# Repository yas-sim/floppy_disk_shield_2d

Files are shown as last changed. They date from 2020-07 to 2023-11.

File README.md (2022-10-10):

# Floppy Disk Shield for Arduino UNO

## Caveat and Disclaimer - Read before you build a fd-shield  

- I don't own any responsibility for the data loss or physical damage on your floppy disks or computer assets caused by the use of hardware and software included in this project.
- Hardware compatibility (especially, FDD and FD-Shield compatibility) is not guaranteed. Your FDD may now work with the FD-Shield.  
- The magnetic flux power on the old floppy disks are dropping and getting weak as time passes. Read-out data integrity with this system is not guaranteed.
- Recommended to use newer FDD. The old FDD may have problems on the magnetic head such as contamination, worn out or mechanical misalignment.

## Announcement  
23-Sep 2022 : Preview release - Feature to write back the floppy images to FD is supported. Use `duplicate.py` to write the `*.raw` floppy image data to a floopy disk. Arduino firmware update and closing `JP5` on the fd-capture shield are required to enable the feature.   
23-Sep 2022 : Preview release - イメージの書き戻しもできるようになりました。Arduinoファームウエアの更新と`JP5`ジャンパーのショートをすると書き込みができるようになります。   

## Description
This is a project to develop a system for preserving old 2D/2DD floppy disk data.  
The system can preserve entire floppy disk data regardless whether it's normal or not. That means the system can read and preserve copy protect information in the bit-stream file as it is.  
The recorded bit-stream file can be decoded and restore the contents anytime later.  
The system includes a bit-stream data to D77/D88 emulator disk image converter. You can read the floppy disk with this tool and generate the disk images.  
これは古い2D/2DDフロッピーディスクのデータを保存するためのシステムを作るプロジェクトです。  
このシステムを使うことで仕様にのっとった正しい信号も非正規の信号も全てそのまま保存することが可能です。つまり、このシステムではコピープロテクトのための情報まで含めてビットストリームデータとして保存することが可能です。  
記録されたビットストリームデータは後でデコード、解読を行うことで情報を取り出すことが可能です。  
このシステムにはビットストリームデータからエミュレータ互換のイメージファイル(D77/D88)を生成するためのコンバーターも含んでいます。実際のフロッピーを読み取り、ディスクイメージを生成することが可能です。  

The system consists of the hardware and software:  
システムはハードウエアとソフトウエアから構成されます:

**Hardware**  
|Item|Description|
|:----|:----|
|Arduino UNO|Arduino UNO. The firmware uses ATMega328 specific regiter. The other Arduino board may not work|
|Floppy disk shield for Arduino|Design data is included. Both schematics and PCB data are available (`./kicad/*`)<br>Rev.A design has bugs. Rev.B and beyond are basically comatible and has same function.<br>KiCAD用のPCBの設計データも提供されています(./kicad/*)<br>Rev.A and Rev.Fにはバグがあります。Rev.B以降は基本的に同じ機能です|
|Floppy disk drive|2D/2DD/2HD FDD. 3.5" or 5.25" FDD (+ power supply and ribbon cable). 300rpm drive is recommended but 360rpm 2HD drive will work as a 2DD drive. The FD-shield can detect the track density (2D or 2DD/2HD, 80 tracks or 160 tracks) and spindle spin speed (300rpm or 360rpm)|  

**Software**  

|Name|Description|
|:---|:---|
|[`fdcapture.ino`](./docs/fdcapture_ino.md)|Arduino firmware (sketch) for the floppy shield<br> (`./fdcapture/fdcapture.ino`)|
|[`capture.py`](./docs/capture.md)|Floppy image capture tool (FD->image).<br>Transfers raw bitstream data from Arduino to a PC (foremerly, `transfer.py`)|
|[`duplicate.py`](./docs/duplicate.md)|Floppy image write back tool (image->FD).<br>Transfers raw bitstream data from a PC to Arduino. Close '`JP5`' jumper pad on the FD capture shield to enable the write feature.|
|[`bs2d77.py`](./docs/bs2d77.md)|Bit-stream data (.raw) to emulator disk image (D77/D88) converter.<br> The program generates modified D77 image data (D77mod). D77mod specification is [here](docs/D77mod_format.md). The D77mod uses some reserved bytes in the header but it is designed to keep backward compatibility with the standard D77 disk images. The D77mod image should work with emulators which supports regular D77/D88 disk images.|
|[`bs2hfe`](./docs/bs2hfe.md)|Bit-stream data (.raw) to .HFE floppy image format.<br>The .hfe disk image format is used for the [HxC FDD emulator device](https://hxc2001.com/download/floppy_drive_emulator/).|
|[`bs_inspect.py`](./docs/bs_inspect.md)|Data inspection/analyze tool for bit-stream data|
|[`d77_inspect.py`](./docs/d77_inspect.md)|Data inspection/analyze tool for D77/D88 disk image data|
|`floppylib.py`|A library which provides fundamental floppy disk functions.<br> This library is including data-separator, digital VFO, MFM decoder and IBM format parser|
|`d77dec.py`|Convert a D77/D88 disk image data to a JSON (plane text) file|
|`d77enc.py`|Generate a D77/D88 disk image data from a JSON file|
|`d77lib.py`|A libray which provides basic D77/D88 floppy disk image manipulation functions|
|[`kfx2bs.py`](./docs/kfx2bs.md)|[**KyroFlux**](https://www.kryoflux.com/) raw-bitstream data to fd-shield bit-stream data converter. You can capture FD image with KryoFlux and use it.|

### Updates  
|Date|Description|
|-|-|
|Sep 2022|Updated PCB design. Changed the 'Write Gate' jumper from jumper pad to jumper pin header for easy setting.|
|Sep 2022|Added support for the image write back feature (image->fd). Arduino firmware update and closing `JP5` on the fd-capture shield are required to enable the feature.|
|Sep 2022|Added RAW to HFE file converter (bs2hfe.py)|
|Aug 2022|Backported data-separator and VFO algorithm from [fdc_bitstream](https://github.com/yas-sim/fdc_bitstream) project. The latest VFO algorithm improved the accuracy of the data reading / decoding.|

## fdc_bitstream  
The [`fdc_bitstream`](https://github.com/yas-sim/fdc_bitstream) is my project that provides a bit-accurate C++ software FDC library. The fdc_bitstream project includes a disk image converter and image analyzer. Those software are written in C++, so they are faster than the converters in this project. Also, they are developed recently and have better algorithms for format conversion.  Please try `image_converter` in the `fdc_bitstream` project as well.  
[`fdc_bitstream`](https://github.com/yas-sim/fdc_bitstream)はビット精度で正確なソフトウエアFDCを開発するプロジェクトです。fdc_bitstreamプロジェクトにもイメージ変換ツールとイメージ解析ツールが含まれています。これらのツールはC++でかかれており、より高速です。またこちらのほうが開発が後なのでより良いアルゴリズムが使われており、イメージ変換の正確性も上がっています。fdc_bitstreamプロジェクトのimage_converterもお試しください。  

### System Diagram
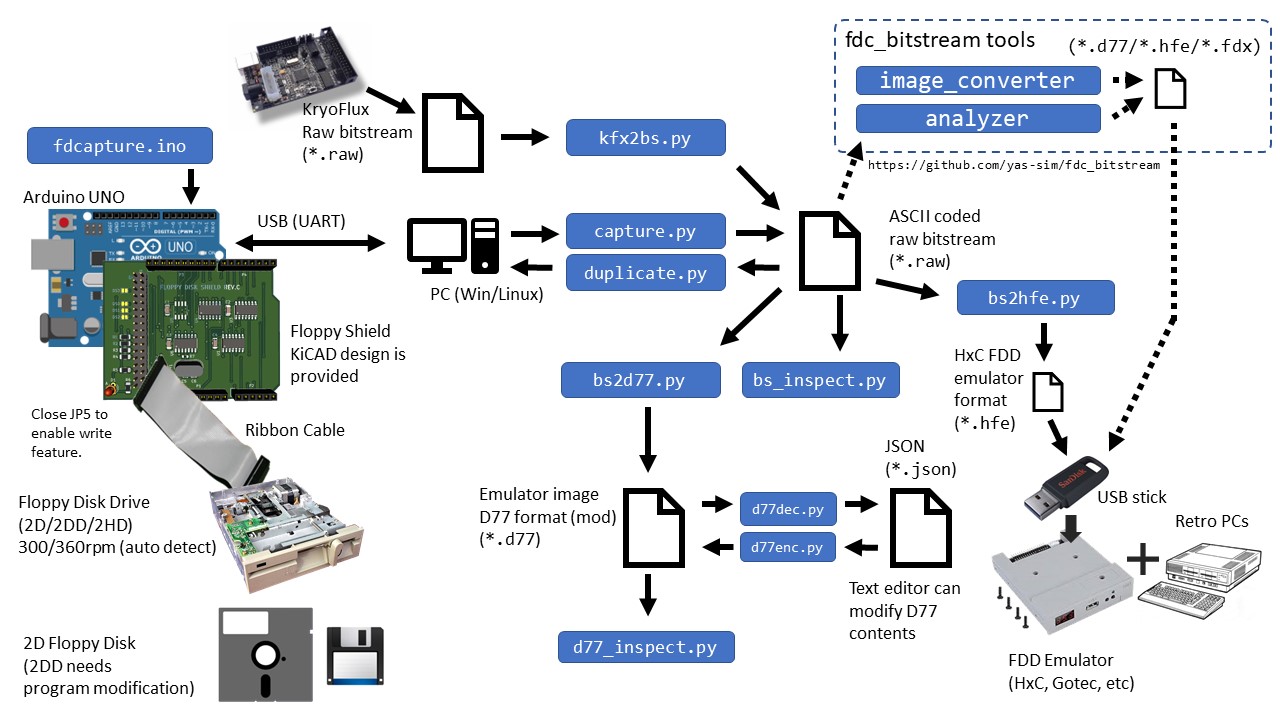
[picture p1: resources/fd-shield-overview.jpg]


## FD-Shield - How It Works
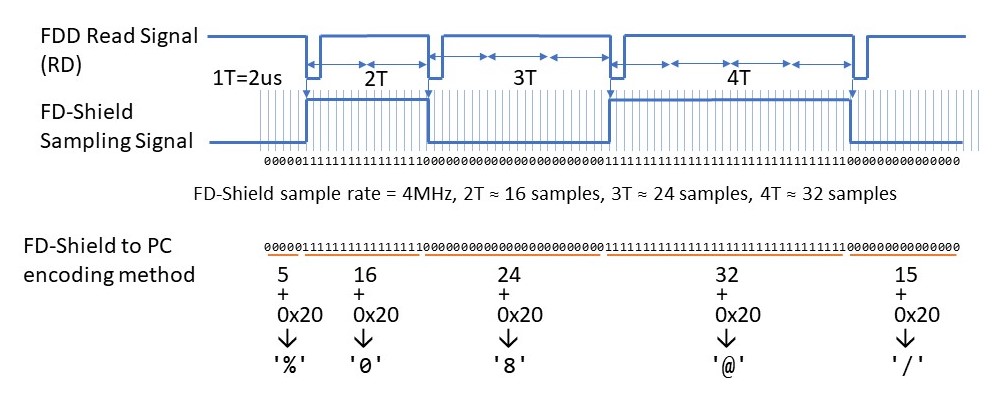
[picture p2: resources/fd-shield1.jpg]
FD_Shield How it works


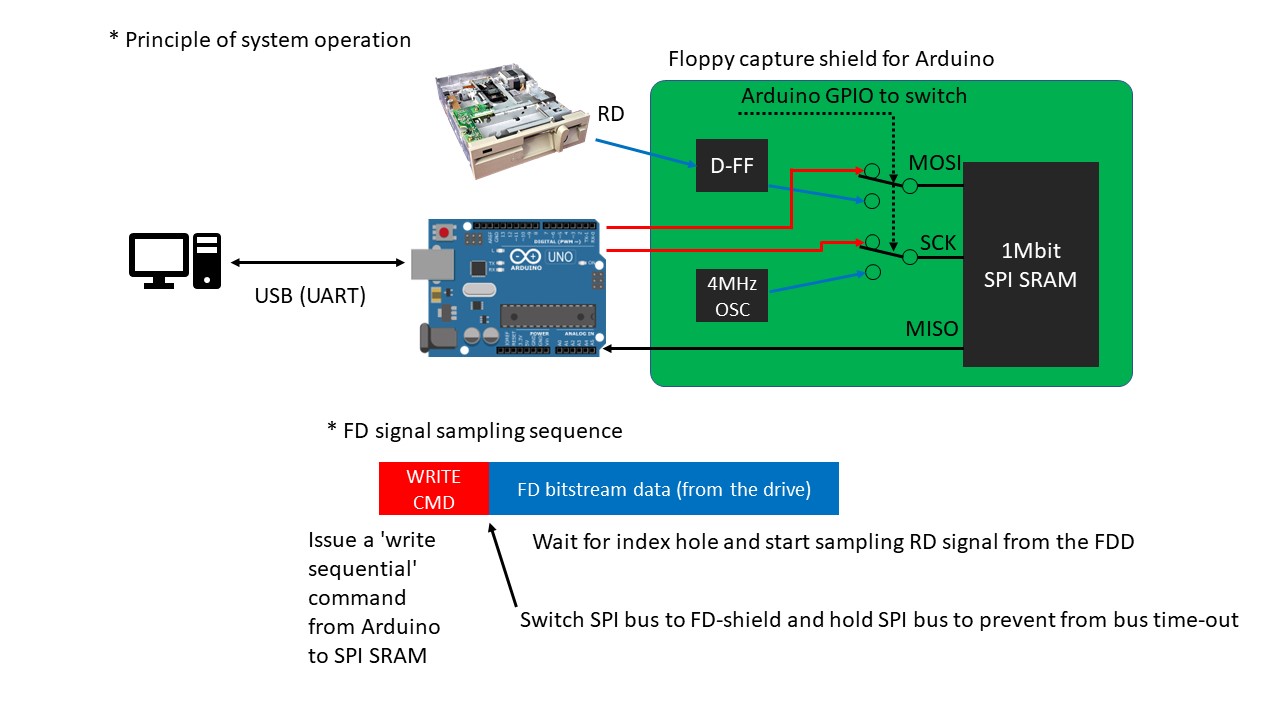
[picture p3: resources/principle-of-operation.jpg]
FD_Shield_Principal_of_operation


---------

## Introduction of Features in the Support Tools

* `bs_inspect.py`  
This tool provides featurs to analyze or check the bitstream data and its quality.  
	* Visualize track data including address mark and sector data occupancies.
	* Visualize data timing history.
	* Visualize data timing histogram.
	* Read all IDs in the tracks.
	* Read all sectors in the tracks.
	* MFM data dump.
	* ASCII data dump (display pritable/readable data).
	* Tweak parameters (VFO high/low gain value, sampling frequency, FDD spin speed) .

### Track visualizer  
You can check the address marks and sector body overlap status with this feature. The entire track data is shown in the window. The yellow vertical line indicates the position of the index hole (it appears when you capture the track data with --read_overlap option). This feature can show the decoded MFM data at the point of the mouse cursor.   

* Legend:  
	* Red ID               : ID CRC Error
	* Green virtical line  : ID AM / Index AM
	* Cyan virtical line   : DAM / DDAM
	* Cyan horizontal line : Sector data (normal)
	* Magenta horizontal line : Sector data (Data CRC error)
	* Red cross mark       : Record not found error
	* Yellow virtical line : Index hole  
<br>  

* Example of a normal track  
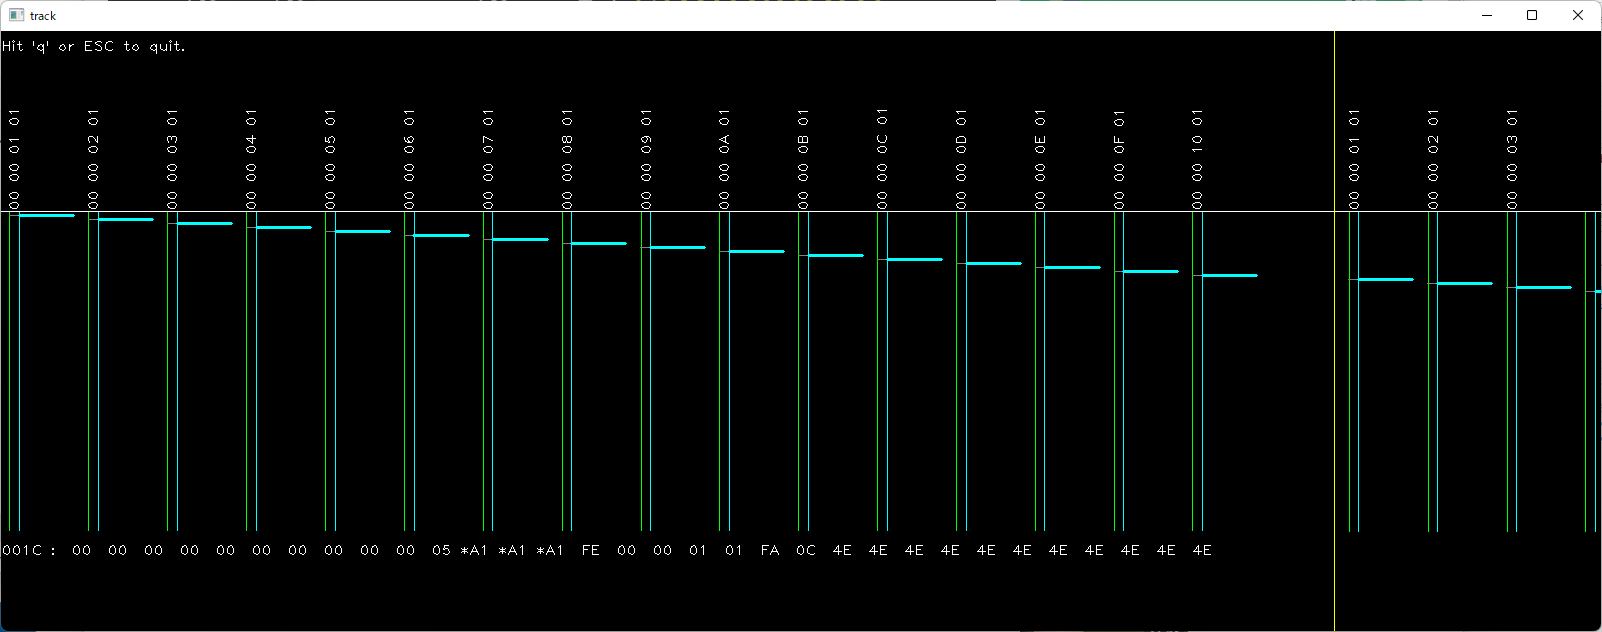
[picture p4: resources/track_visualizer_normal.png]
normal
  

* Example of a protected track  
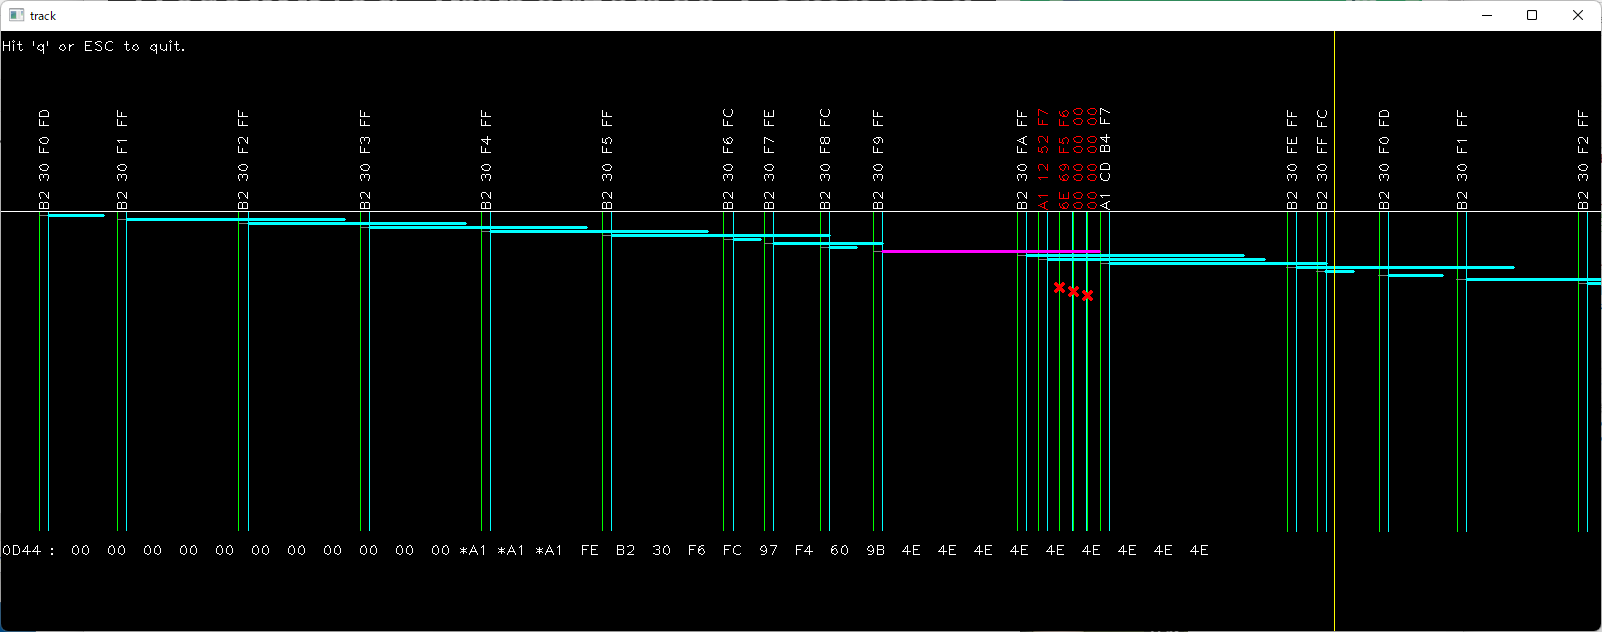
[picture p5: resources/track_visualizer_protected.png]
protected
  

### Bitstream visualizer  
You can check how VFO follows the variation of pulse pitch with the bitstream visualizer.  
The VFO tries to keep the data pulse be the center of the bit cell as much as possible by tweaking the oscillation frequency (= the bit cell width).  
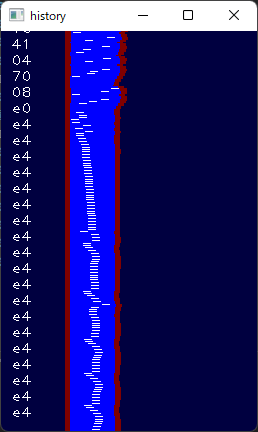
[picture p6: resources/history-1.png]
history-good

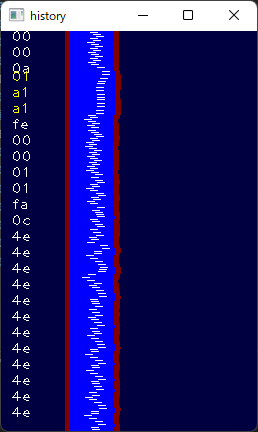
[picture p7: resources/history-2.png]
history-bad
  

### Bitstream timing histogram viewer
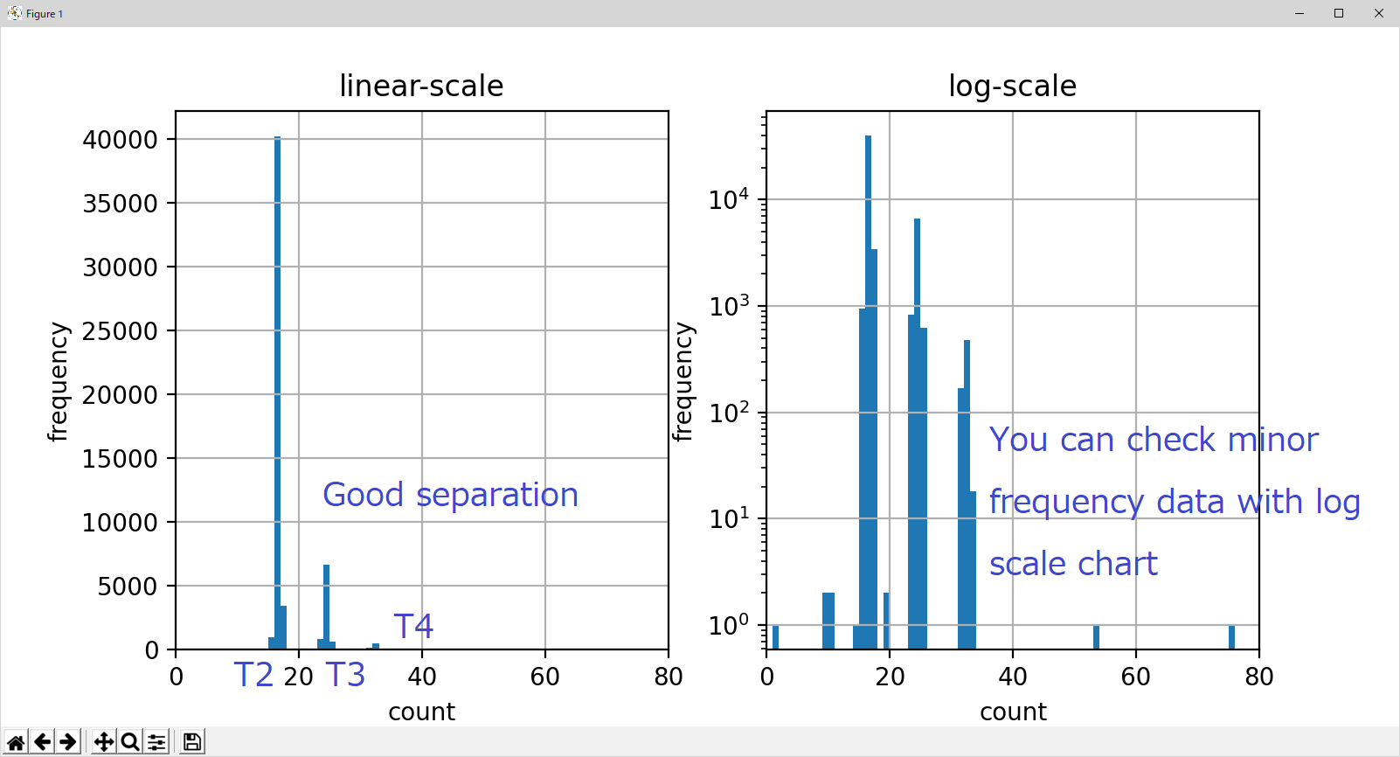
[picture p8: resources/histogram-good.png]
histogram-good
* Good case 
* Bad case - Usually, this may be caused by the spindle speed fluctuation (that causes data pulse pitch variation in a track), or data written by multiple drives (written with drives with different spindle motor speeds).  
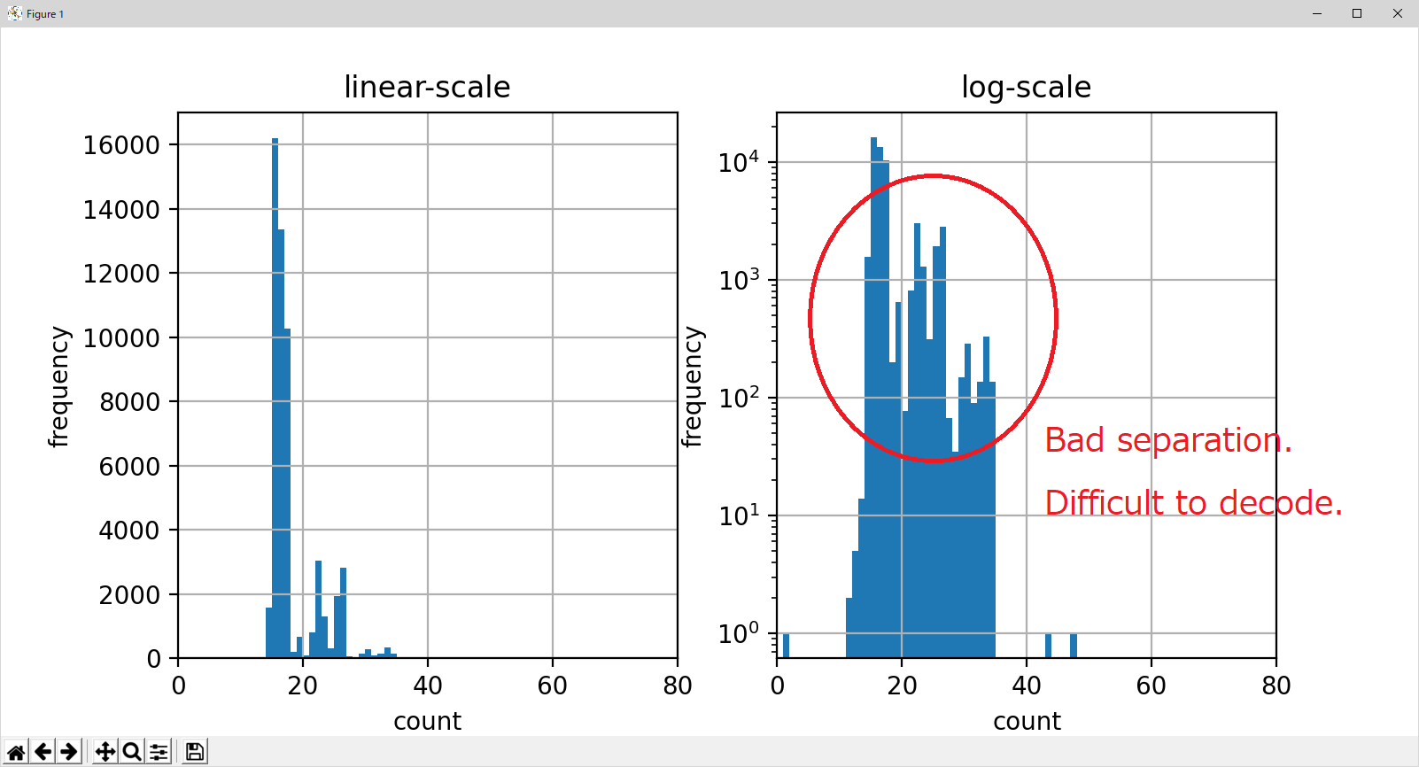
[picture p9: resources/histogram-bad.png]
histogram-bad

  
### Pulse (bit) pitch visualizer  
You can check the pulse pitch fluctuation throughout a track with the pulse pitch visualizer. The stabler pitch, the easier MFM decode or data read.  
- Stable pitch  
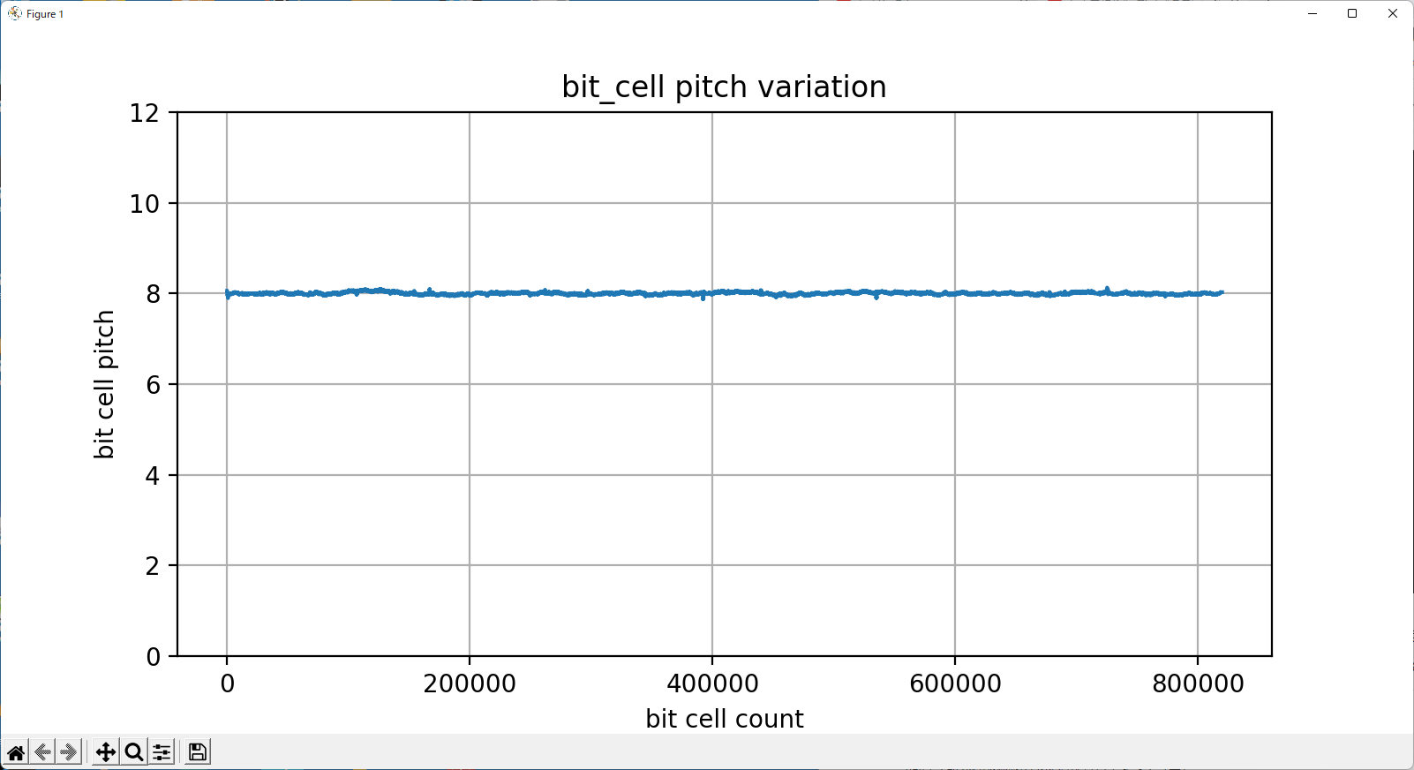
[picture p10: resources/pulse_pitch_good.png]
good pitch

- Unstable pitch. Heavily fluctuated. It's so hard to follow by the VFO. May fail data retrieving.  
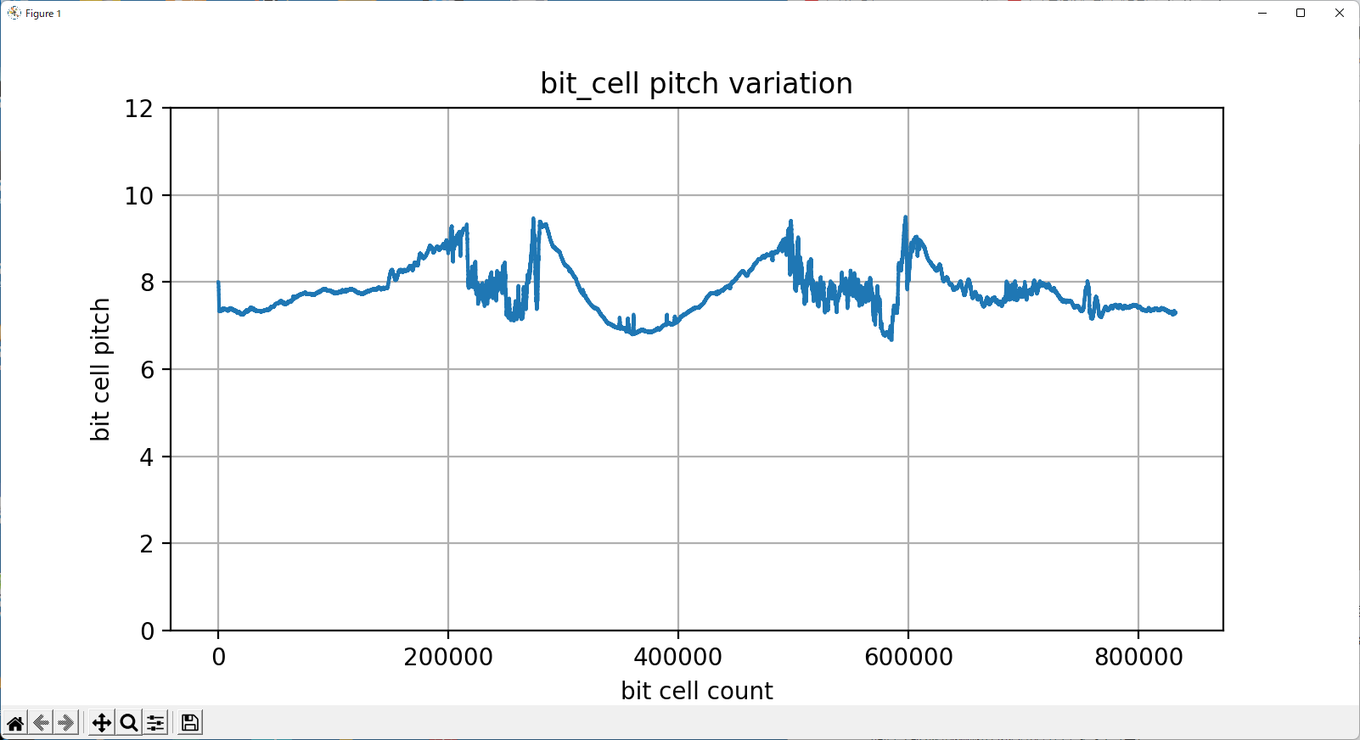
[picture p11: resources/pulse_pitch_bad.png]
bad pitch

 
---------

## How to use (Image capture) - 使い方

1. Build Floppy shield for Arduino UNO - シールド製作  
- PCB design files can be found in the `./kicad` directory
2. Burn the floppy disk shield firmware (sketch) to Arduino UNO - Arduio UNOにファームウエアを書き込む  
Use `fdcapture.ino`
3. Assemble the system - システムを接続
- Attach a floppy shield to an Arduino UNO
- Connect a floppy shield and a floppy disk drive with a 36pin ribon cable
- Connect Arduino UNO to PC via USB cable
4. Read raw bit-stream data from a floppy disk - フロッピーからビットストリームデータを生成  
- Insert a 2D floppy disk to the floppy disk drive (FDD)
- Run following command on the Windows PC:
```sh
python capture.py -o image_name.raw --read_overlap 5 [--media_type 2D|2DD]
```
- `capture.py` will search COM port for Arduino UNO and use it.  
- `--read_overlap` option specifies how much data to read on the 2nd lap in percent.  
- `--media_type` option specifies the media type to read. `2D` or `2DD` are available.  
Note: The `fdcapture.ino` can identify the drive type (2D or 2DD) but not the media type.    
5. Convert raw bit-stream data into emulator image data (D77mod) -- ビットストリームからディスクイメージファイルを生成
```sh
python bs2d77.py -i image_name.raw --abort_id
```
- `image_name.d77` will be generated.  
**Note:** The `--abort_id` option enables abort reading track image when the same sector ID is detected. The FD-shield can read the top of the 2nd lap with `--read_overlap` option. This overlapped track data may contain the same sector data twice. This option will prevent from generating the same sector in a track.  

## Image write back (cloning)  
1. Setup the system as the same as image captureing.  
	- The same `fdcapture.ino` firmware works for both `capture.py' and 'duplicate.y' but updating to the latest firmware is required. Use Arduino IDE to update the firmware (Arduino program).    
	- Close `JP5` jumper pad on the fd-capture shield.  
2. Run '`duplicate.py`' to write back a '`*.raw`' floppy image to a floppy disk.  
```sh
python duplicate.py -i disk_image.raw
```

## How to make your own FD-shield PCB (FD-shield PCBの作り方)  
- PCB design data and the data for PCB manufacturing (Garber data and drill data) are included in this project. You can order your PCB at a PCB manufacturing service company. I used 'Fusion PCB' from Seeed Studio. (cost would be around $35 for 10 PCBs incl. delivery fee)    
- PCB設計データとPCB製造データ(ガーバー、ドリル)はこのプロジェクトに含まれています。PCB製造サービス会社に製造を依頼してPCBを手に入れることができます。私はSeeed StudioのFusion PCBを利用しました。(10枚で4K円くらい？ 送料込み)   

|File|Description|  
|---|---|
|pcb_mfg_data/fdshield-dip-rev-h.zip|PCB manufacturing data. DIP version. Rev.H (Write Gate pin header)|  
|kicad/fdshield-dip/fdshield/fdshield.kicad_pro|KiCad v6 design file (DIP)|  
|kicad/fdshield-sop/fdshield/fdshield.kicad_pro|KiCad v6 design file (SOP)|  

## Accessory Tools  
1. FDD spindle motor speed calibration tool  
This tool measures the index hole to index hole time and show it on the screen. You can tweak a variable register on the FDD control board to adjust the spindle speed.  
**CAUTION**: There might be multiple variable registers on the FDD control board. If you are unsure which one is the right one, do not turn it, or your FDD will become unfunctional.  
- How to use:  
	1. Set up `fdcapture` shield - Connect Arduino UNO, fdcapture shield, and FDD.   
	2. Insert a floppy disk into the FDD.  
	3. Run `spindle_calibration_tool.py`

## Current Development Status
**Done:**
- Read floppy disk images (2D disk on 2D drive, 2DD disk on 2D deive, 2D disk on 2DD/2HD drive)
- Write floppy disk image to floppy disk (2D images are tested)  
- Drive type auto datection (2D or 2DD/2HD)
- Drive spindle revolution measurement 
- Generates D77mod disk images from the raw bitstream data (RAW->D77)
- RAW->HFE file converter
- Bit stream file quality inspection tool (bs_inspect.py)

## Test Environment

- Windows 10 1909 / Windows 11 21H2
- Arduino UNO
- Floppy disk shield for Arduino
- FDDs (table below)

|P/N|Mfg|FF|Description|
|:----|:----|:----:|:----|
|YD-580 1354|YE-Data|5.25"|2D, 300rpm, for Fujitsu FM-7|
|MD5201|Canon|5.25"|2D, 300rpm|
|FD-55B-01-U 19307110-01|TEAC|5.25"|2D, 300rpm|
|FD55-GFR 19307673-93|TEAC|5.25"|2DD/2HD, 360rpm, for DOS/V|
|YD625-1525|YE-Data|3.5"|2D, 300rpm, for Fujitsu FM-77|
|FD-235HG 19307773-04|TEAC|3.5"|2DD/2HD, 300/360rpm, Fixed to DS1|
|OSD E26J|Citizen|3.5"|2DD/2HD, 300/360rpm, for PX9821Xa?|
|JU-256A236P|Panasonic|3.5"|2DD/2HD, 300/360rpm, for DOS/V|
|FD1231T 134-506790-011-0|NEC|3.5"|2DD/2HD, 300/360rpm, for PC9821|
|DF354H068C|ALPS|3.5"|2DD/2HD, 300/360rpm, for DOS/V|

---------------

## Addendum

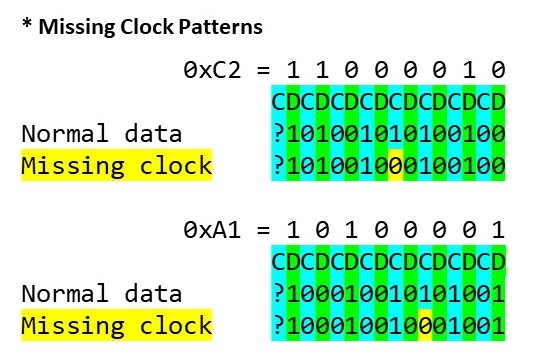
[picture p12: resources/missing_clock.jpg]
MFM Missing Clock Patterns


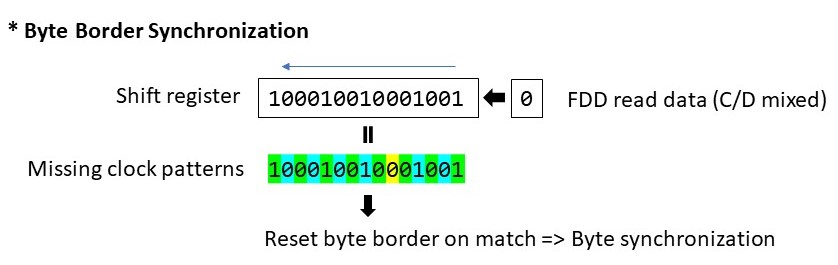
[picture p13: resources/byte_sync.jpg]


### FD-shield - 3D view
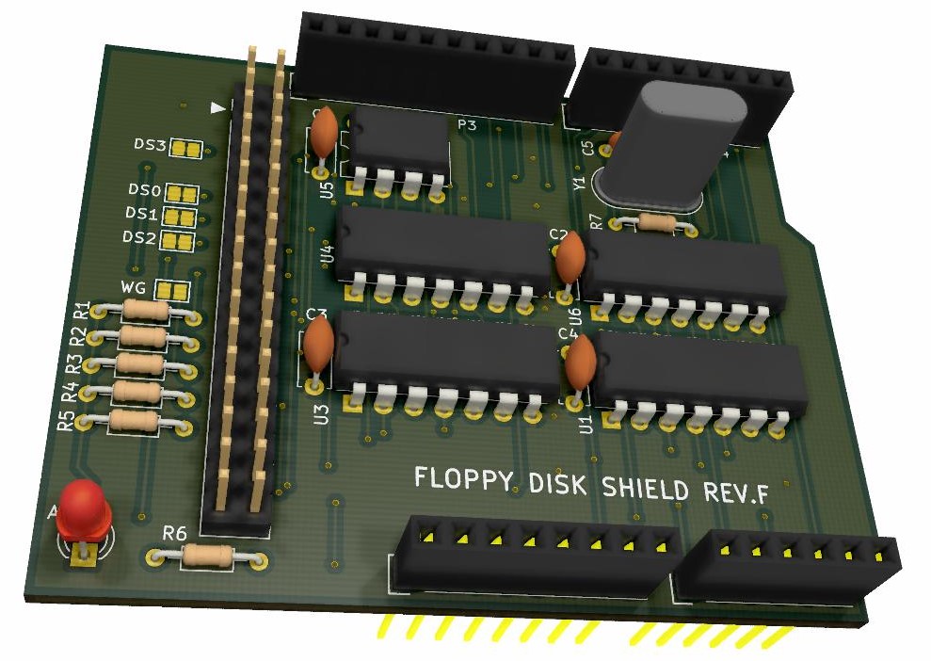
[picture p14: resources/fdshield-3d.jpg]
3D
  
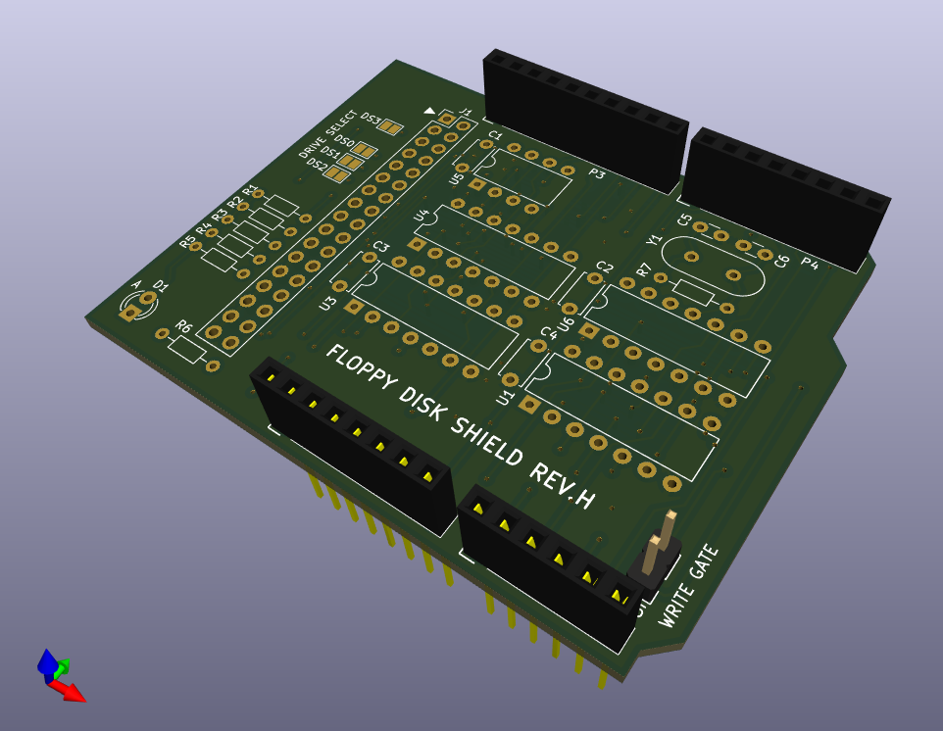
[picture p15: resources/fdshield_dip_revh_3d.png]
3D_dip
  
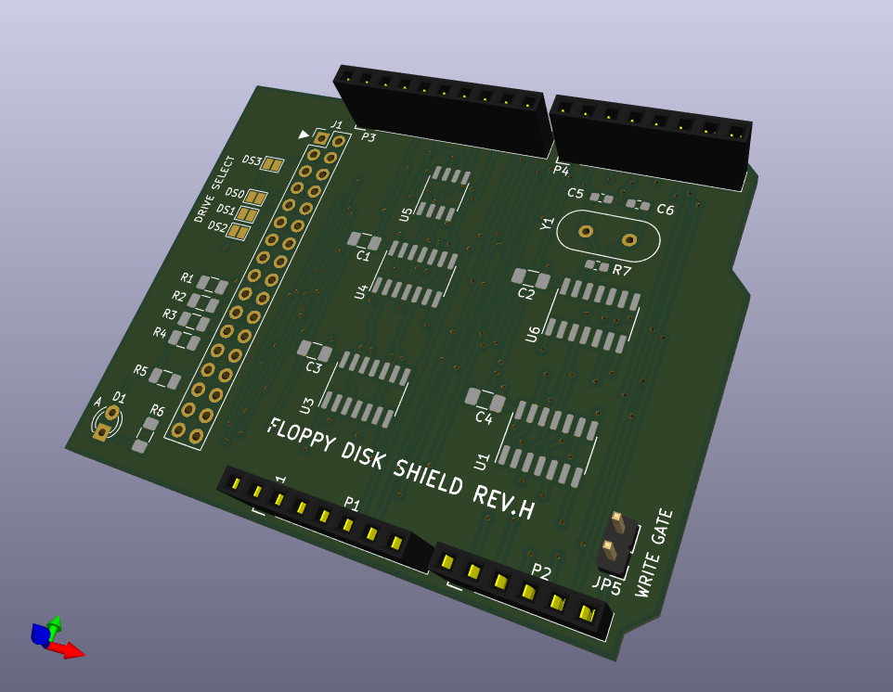
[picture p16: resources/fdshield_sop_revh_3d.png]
3D_sop
  

### FD-shield - Schematics  
Y1 (Xtal) = 4MHz X'tal.  
U6 must be '74HC**U**04' (unbuffered type). The standard '74HC04' doesn't work.  
The other logic ICs can be either one of '74LS' or '74HC'.  
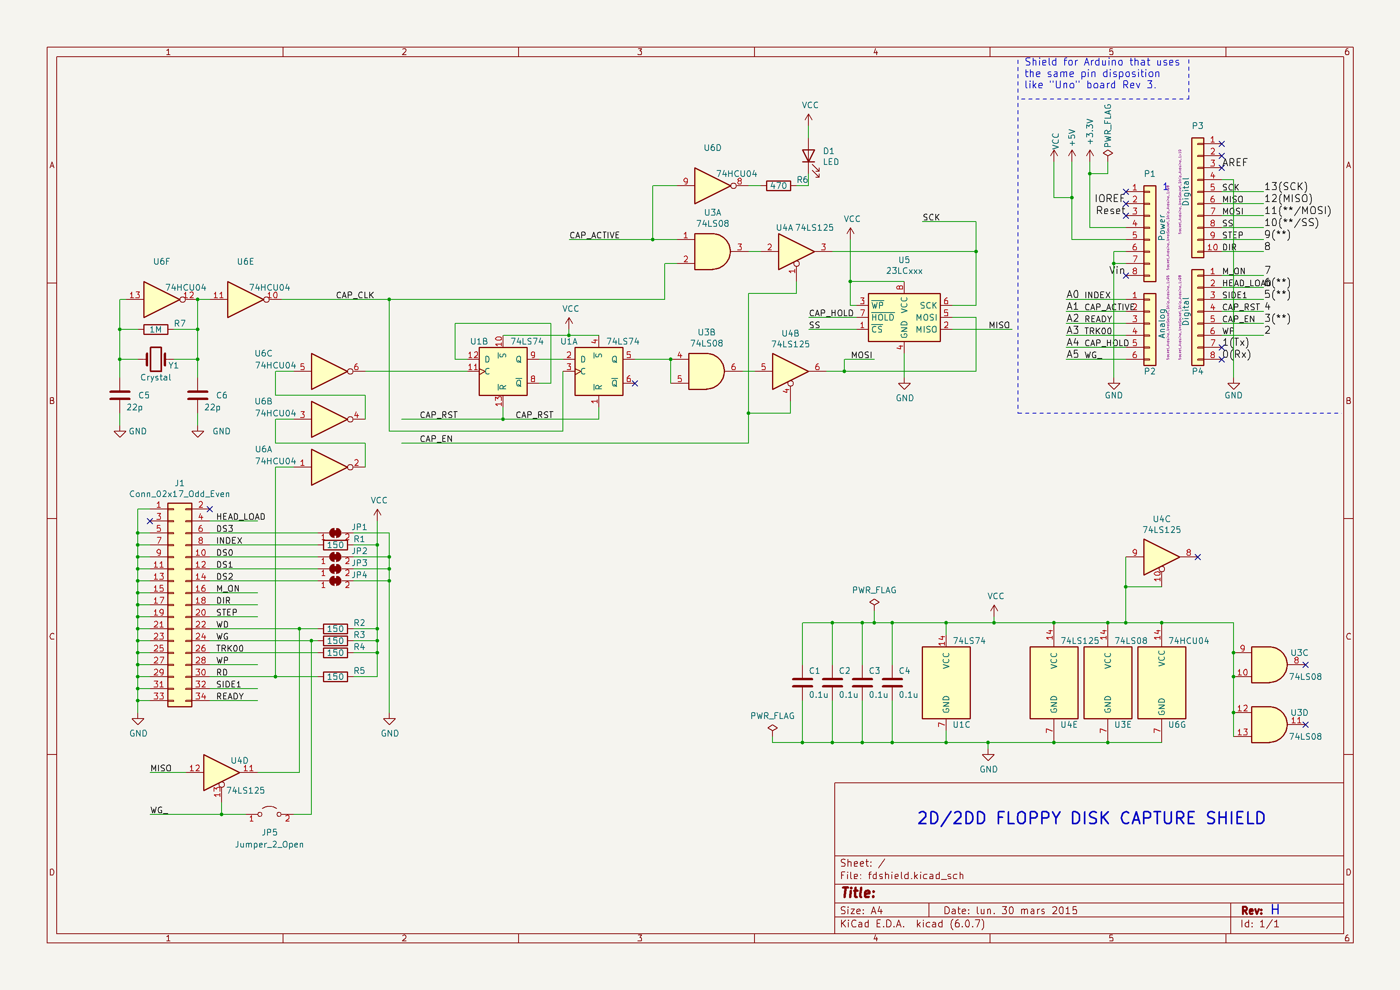
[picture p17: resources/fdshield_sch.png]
schematics

[PDF](resources/fdshield-schematics.pdf)

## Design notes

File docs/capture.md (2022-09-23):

# capture.py

This program transfers the raw bit stream FD data from the Arduino FD-cautpre shield to the host PC.  

```sh
usage: capture.py [-h] -o OUTPUT [--start_track START_TRACK]
                   [--end_track END_TRACK] [--media_type MEDIA_TYPE]
                   [--read_overlap READ_OVERLAP]

optional arguments:
  -h, --help            show this help message and exit
  -o OUTPUT, --output OUTPUT
                        output raw bit stream file name (Default =
                        fdshield_(DATE-TIME).raw)
  --start_track START_TRACK
                        start track number
  --end_track END_TRACK
                        end track number
  --media_type MEDIA_TYPE
                        media type (2D, 2DD or 2HD)
  --read_overlap READ_OVERLAP
                        track read 2nd lap overlap percentage (default = 0
                        percent)
```

- Read a 2D disk  
```sh
python capture.py -o image.raw
```

- Read a 2DD disk with 5% read overlap (read 105% of track from the index hole)
```sh
python capture.py -o image.raw --medi_type 2DD --read_overlap 5
```

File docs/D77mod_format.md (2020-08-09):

# D77mod Disk Image Format Specifications

**Header (0x2b0 bytes)**
|offset|size|Contents|
|:----:|:----:|:----|
|0x0000|17|image name (ASCIIZ)|
|0x0011|1|<span style="color: blue; ">(mod)**raw track data support flag (0x00=not support, 0x10=supported)**</span>|
|0x0012|8|reserve (0x00)|
|0x001a|1|write protect flag (0x00: no protect, 0x10: write protected)|
|0x001b|1|disk type (0x00: 2D, 0x10: 2DD, 0x20: 2HD)|
|0x001c|4|total disk image size|
|0x0020|4 * 164 (0x290)|sector data table (0-163 track)|
|0x02b0|4 * 164 (0x290)|<span style="color: blue; ">(mod)**track data table (0-163 track) 0=No track data or dirty track**</span>|
  
<br>

<span style="color: blue; ">**(mod)Track data (+0x540 (=0x20+0x290+0x290))**</span>  
|offset|size|contents|
|:----:|:----:|:----|
|0x0000|4|<span style="color: blue; ">(mod)**track data size**</span>|
|0x0004|variable|<span style="color: blue; ">(mod)**track data**</span>|

<br>
  
**Sector data** (+0x2b0 when without track data, +??? with track data)  
|offset|size|contents|
|:----:|:----:|:----|
|0x0000|1|C|
|0x0001|1|H|
|0x0002|1|R|
|0x0003|1|N|
|0x0004|2|# of sectors in this track|
|0x0006|1|density (0x00: double density, 0x40: single density)|
|0x0007|1|Deleted data (0x00: normal, 0x10: deleted data)XM7: 0x10 => RECORD_TYPE_ERR|
|0x0008|1|status (0x00: normal end, others: disk BIOS status) XM7: 0xb0 => Data CRC_ERR|
|0x0009|2|<span style="color: blue; ">(mod)**sector position (MFM byte)**</span>|
|0x000b|1|<span style="color: blue; ">(mod)**Status extension. 0x01 = ID_CRC error**</span>|
|0x000c|2|<span style="color: blue; ">(mod)**ID_CRC values**</span>|
|0x000e|2|sector size|
|0x0010|variable|sector data|

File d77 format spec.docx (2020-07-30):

Header (0x2b0 bytes)

offset | size | contents
0x0000 | 17 | image name (ASCIIZ)
0x0011 | 1 | raw track data support flag (0x00=not support, 0x10=supported)
0x0012 | 8 | reserve (0x00)
0x001a | 1 | write protect flag (0x00: no protect, 0x10: write protected)
0x001b | 1 | disk type (0x00: 2D, 0x10: 2DD, 0x20: 2HD)
0x001c | 4 | Disk size
0x0020 | 4 * 164 (0x290) | sector data table (0-163 track)
0x02b0 | 4 * 164 (0x290) | track data table (0-163 track) 0=No track data or dirty track

Track data (+0x540)

offset | size | contents
0x0000 | 4 | track data size
0x0004 | variable | track data

Sector data

offset | size | contents
0x0000 | 1 | C
0x0001 | 1 | H
0x0002 | 1 | R
0x0003 | 1 | N
0x0004 | 2 | # of sectors in this track
0x0006 | 1 | density (0x00: double density, 0x40: single density)
0x0007 | 1 | Deleted data (0x00: normal, 0x10: deleted data) XM7: 0x10 => RECORD_TYPE_ERR
0x0008 | 1 | status (0x00: normal end, others: disk BIOS status) XM7: 0xb0 => Data CRC_ERR
0x0009 | 2 | sector position (MFM byte)
0x000b | 1 | Status extension 0x01 = ID_CRC error
0x000c | 2 | ID_CRC
0x000e | 2 | sector size
0x0010 | variable | sector data

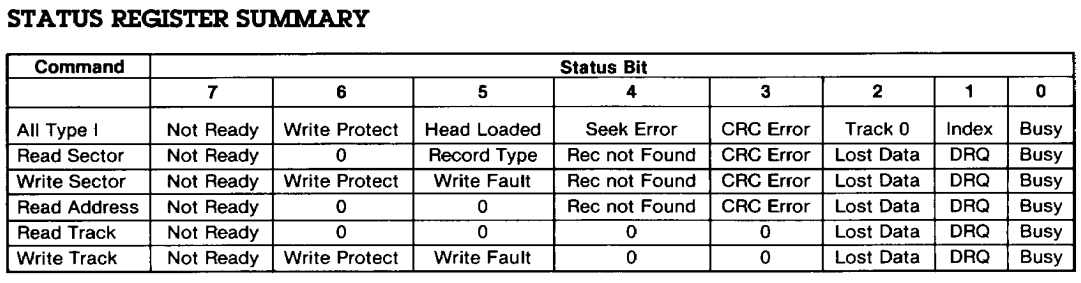
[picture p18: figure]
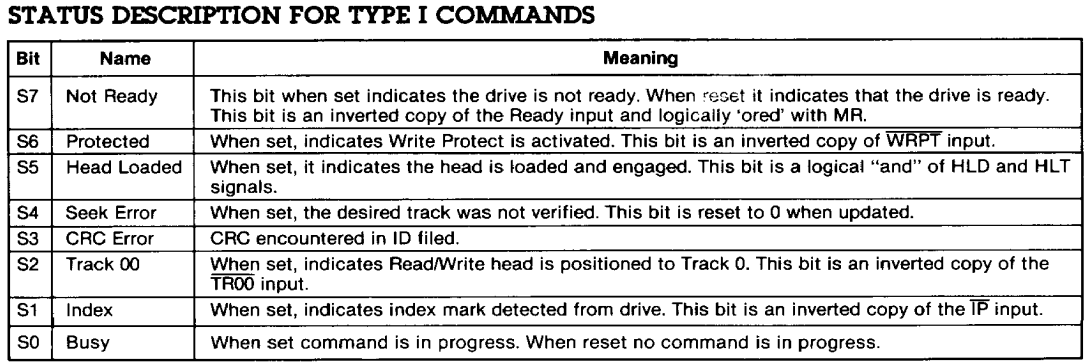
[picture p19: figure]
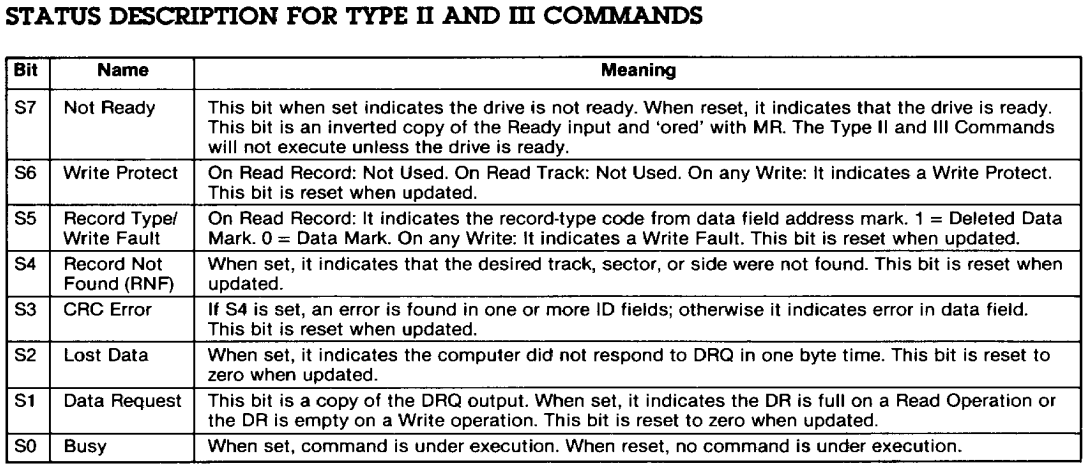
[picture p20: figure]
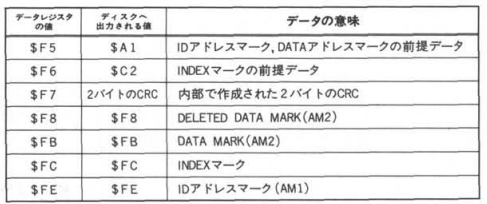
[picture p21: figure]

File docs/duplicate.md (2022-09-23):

# duplicate.py

'*.raw' floppy disk image write back tool. This program transfers a raw bit stream FD data from a host PC to an Arduino.  

Note: 'JP5' on the fd-capture shield must be closed to enable write feature.  

```sh
usage: duplicate.py [-h] -i INPUT.raw

optional arguments:
  -h, --help            show this help message and exit
  -o INPUT, --input INPUT
                        input raw bit stream file name
```

- Read a 2D disk  
```sh
python duplicate.py -i image.raw
```

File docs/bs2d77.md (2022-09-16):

# bs2d77.py

Convert a RAW FD bit stream file (.raw) into a FM-7/FM77AV emulator disk format (.d77).  
Virtually the D77 disk image format and D88 disk image format are identical. You can use the D77 disk image with the emulator software for the PC-8801 series by just modifying the file extension.    

```sh
usage: bs2d77.py [-h] -i INPUT [-o OUTPUT] [--high_gain HIGH_GAIN]
                 [--low_gain LOW_GAIN] [--log_level LOG_LEVEL]
                 [--clk_spd CLK_SPD] [--abort_index] [--abort_id]
```

|option|description|
|-|-|
|-h, --help|show this help message and exit|
|-i INPUT, --input INPUT|input image file path|
|-o OUTPUT, --output OUTPUT|output D77 image path|
|--high_gain HIGH_GAIN|high-speed data separator gain (default: 0, recommend:0~0.4)|
|--low_gain LOW_GAIN|low-speed data separator gain (default: 0, recommend: 0~high_gain)|
|--log_level LOG_LEVEL|log level: 0=off, 1=minimum, 2=verbose|
|--clk_spd CLK_SPD|FD-shield capture clock speed (default=4MHz=4000000)|
|--abort_index|abort ID reading on 2nd index mark detection (Default=False)|
|--abort_id|abort ID reading on 2nd identical ID detection (Default=True)|

## Command line example  
```sh
python bs2d77.py -i bitstream.raw --abort_id
** Floppy shield bit-stream data to D77 image converter
Spin speed: 198.85759 ms
000 16/00   001 16/00   002 16/00   003 16/00   004 16/00   005 16/00
006 16/00   007 16/00   008 16/00   009 16/00   010 16/00   011 16/00
012 16/00   013 16/00   014 16/00   015 16/00   016 16/00   017 16/00
018 16/00   019 16/00   020 16/00   021 16/00   022 16/00   023 16/00
024 16/00   025 16/00   026 16/00   027 16/00   028 16/00   029 16/00
030 16/00   031 16/00   032 16/00   033 16/00   034 16/00   035 16/00
036 16/00   037 16/00   038 16/00   039 16/00   040 16/00   041 16/00
042 16/00   043 16/00   044 16/00   045 16/00   046 16/00   047 16/00
048 16/00   049 16/00   050 16/00   051 16/00   052 16/00   053 16/00
054 16/00   055 16/00   056 16/00   057 16/00   058 16/00   059 16/00
060 16/00   061 16/00   062 16/00   063 16/00   064 16/00   065 16/00
066 16/00   067 14/02   068 16/00   069 16/00   070 16/00   071 03/13
072 16/00   073 15/01   074 16/00   075 12/04   076 16/00   077 03/13
078 16/00   079 06/10
Adding raw track image data (MFM only)
 1237 sectors read (no error)
   43 error sectors
16.0 sectors in a track (average)
```
* Track status  
  `Track# read_sectors/error_sectors`
  E.g. `067 14/02` -> 14 sectors read and 2 error sectors (mainly data CRC error). `--abort_id` direct program to abort data reading when a sector which has the identical ID (CHRN) is found in a track (<= Usually, this happens when the track data is over read to the 2nd lap).

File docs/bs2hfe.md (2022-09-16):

# bs2hfe.py

Convert a RAW FD bit stream file (.raw) into a disk image for the HxC FDD emulator device (.hfe).  

```sh
usage: bs2hfe.py [-h] -i INPUT [-o OUTPUT] [--log_level LOG_LEVEL] [--clk_spd CLK_SPD]
```

|option|description|
|-|-|
|-h, --help|show this help message and exit|
|-i INPUT, --input INPUT|input image file path|
|-o OUTPUT, --output OUTPUT|output D77 image path|
|--log_level LOG_LEVEL|log level: 0=off, 1=minimum, 2=verbose|
|--clk_spd CLK_SPD|FD-shield capture clock speed (default=4MHz=4000000)|

## Command line example
```
python bs2hfe.py -i diskimage.raw -o diskimage.hfe
** Floppy shield bit-stream data to HFE image converter
Spin speed: 199.13520000000003 ms
Conversion completed.
```

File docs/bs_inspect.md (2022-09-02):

bs_inspect.py

```
** Floppy data capture shield - bit stream data inspect tool
usage: bs_inspect.py [-h] -i INPUT -t TRACK [--high_gain HIGH_GAIN]
                     [--low_gain LOW_GAIN] [--log_level {0,1,2}]
                     [--clk_spd CLK_SPD] [--histogram] [--history]
                     [--mfm_dump] [--ascii_dump] [--id_dump] [--read_sectors]
                     [--abort_index] [--abort_id]

optional arguments:
  -h, --help            show this help message and exit
  -i INPUT, --input INPUT
                        input bitstream file path
  -t TRACK, --track TRACK
                        track number. single number or a tuple (start,end)
                        (track # should be 0-83 for 2D, 0-163 for 2DD)
  --high_gain HIGH_GAIN
                        data separator gain for high-speed tracking mode
                        (default: 1)
  --low_gain LOW_GAIN   data separator gain for low-speed tracking mode
                        (default: 1)
  --log_level {0,1,2}   log level: 0=off, 1=minimum, 2=verbose
  --clk_spd CLK_SPD     FD-shield capture clock speed (default=4MHz=4000000)
  --histogram           display histogram of the pulse interval buffer
  --pulse_pitch         display pulse pitch graph for a track
  --history             display history graph of the pulse interval buffer
  --mfm_dump            display MFM decoded data in HEX dump style
  --ascii_dump          display printable data in the sectors
  --id_dump             display decoded all ID address marks in the track
  --read_sectors        read all sectors in the track and display result
  --abort_index         abort ID reading on 2nd index mark detection
  --abort_id            abort ID reading on 2nd identical ID detection
```

```sh
python bs_inspect.py -i gutchan_bank.raw -t 0 --histogram
```
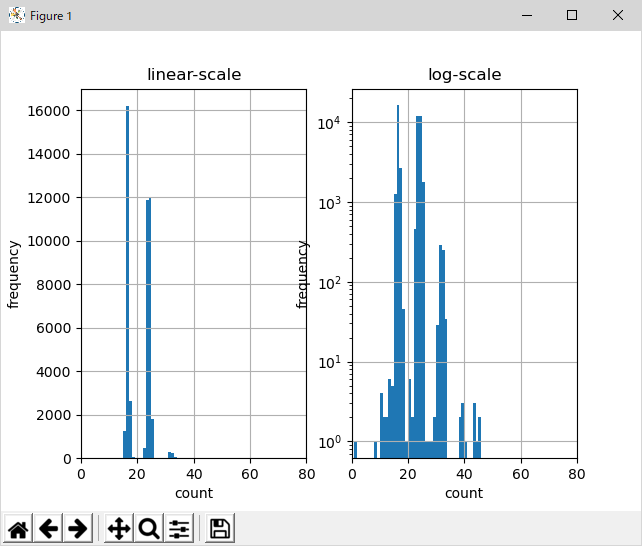
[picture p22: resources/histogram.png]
histogram
  

```sh
python bs_inspect.py -i gutchan_bank.raw -t 0 --history
```
`ESC` to quit, `SPACE` to pause scrolling.  
history  

```sh
python bs_inspect.py -i disk_img.raw -t 0 --pulse_pitch
```
pitch  
pitch  

```sh
python bs_inspect.py -i gutchan_bank.raw -t 0 --mfm_dump
```
```
** Floppy data capture shield - bit stream data inspect tool
** TRACK  0
7614 (0x1dbe) bytes read
  39  39  39  39  39  39  39  39  39  39  39  39  39  39  39  39  39  39  39  39  39  39  39  39  39  39  39  39  39  39  39  39
  39  39  39  39  39  39  39  39  39  39  39  39  39  39  39  39  39  39  39  39  39  39  39  39  39  39  39  39  39  39  39  39
  39  39  39  39  39  39  39  39  39  39  39  39  38  00  00  00  00  00  00  00  00  00  00  00  03 *02 *C2 *C2  FC  4E  4E  4E
  4E  4E  4E  4E  4E  4E  4E  4E  4E  4E  4E  4E  4E  4E  4E  4E  4E  4E  4E  4E  4E  4E  4E  4E  4E  4E  4E  4E  4E  4E  4E  4E
  4E  4E  4E  4E  4E  4E  4E  4E  4E  4E  4E  4E  4E  4E  4E  00  00  00  00  00  00  00  00  00  00  00  00 *14 *02 *A1 *A1  FE
  00  00  01  01  FA  0C  4E  4E  4E  4E  4E  4E  4E  4E  4E  4E  4E  4E  4E  4E  4E  4E  4E  4E  4E  4E  4E  4E  00  00  00  00
  00  00  00  00  00  00  00  00  00 *14 *02 *A1 *A1  FB  1A  50  10  CE  02  B6  86  FD  1F  8B  86  80  97  1D  8D  68  86  05
  8D  4B  8D  16  86  01  8D  3E  86  0F  8D  25  8E  10  00  BF  01  5D  86  05  BD  01  8C  7E  10  00  8D  4A  86  03  97  18
  21  FE  21  FE  21  FE  21  FE  8D  3C  96  18  85  04  27  EA  39  8D  33  97  1B  8D  2F  86  13  97  18  8D  33  96  18  85
  10  27  02  20  EC  39  8D  1E  97  1C  39  00  00  34  06  CC  00  00  C3  00  01  26  FB  35  06  4A  26  F1  39  34  02 *04
  0E  39  84  80  04  03  CC  1F *C2  0E  33  93  E4  80  0C  03  CC  1F *C2  0E  03  81  FC  80  0C  03  C3  00  02  06  02  0E
  33 *42  7E  47  C9  C1  0E  7F  E1  C1  39  80  33  38  07  F0  01  03  1F  21  07  02  03  C1  C0  FE  40  1E  7F  C1  07  00
  40  7E  78  3E  13  FF  FF  FF  FC  00  00  00  00  00  00  00  00  00  00  00  00  00  00  00  00  00  00  00  00  00  00  00
  00  00  00  00  00  00  00  00  00  00  00  00  00  00  00  00  00  00  00  00  00  00  00  00  00  00  00  00  00  00  00  00
  00  00  00  00  00  00  00  00  00  00  00  00  00  00  05  97  57  F3  93  93  93  93  93  93  93  93  93  93  93  93  93  93
  93  93  93  93  93  93  93  93  93  93  93  93  93  93  93  93  93  93  93  93  93  93  93  93  93  93  93  93  93  93  93  93
  93  80  00  00  00  00  00  00  00  00  00  00  00 *14 *02 *A1 *A1  FE  00  00  02  01  AF  5F  4E  4E  4E  4E  4E  4E  4E  4E
  4E  4E  4E  4E  4E  4E  4E  4E  4E  4E  4E  4E  4E  4E  00  00  00  00  00  00  00  00  00  00  00  00  00 *14 *02 *A1 *A1  FB
  12  12  12  12  12  12  12  12  12  12  12  12  12  12  12  12  12  12  12  12  12  12  12  12  12  12  12  12  12  12  12  12
 ```

 ```sh
 python bs_inspect.py -i putty\fb30.log -t 2 --ascii_dump
```

```
** Floppy data capture shield - bit stream data inspect tool
** TRACK  2
 # : (C ,H ,R ,N ) ID-CRC DT-CRC AM    MFM-POS
 1 : (01,00,01,01) OK     OK     DAM   0x009c
"#$%&'()-124679:;<=>?@BFGHIKLMNO
 # : (C ,H ,R ,N ) ID-CRC DT-CRC AM    MFM-POS
 2 : (01,00,0c,01) OK     OK     DAM   0x0212

 # : (C ,H ,R ,N ) ID-CRC DT-CRC AM    MFM-POS
 3 : (01,00,07,01) OK     OK     DAM   0x0387
ART-O   +WOMAN-D ,TOKEI-D .DEMO-O  /WAKA1-D 0WAKA2-D 3MICKEY  5OEKAKI7 8
 # : (C ,H ,R ,N ) ID-CRC DT-CRC AM    MFM-POS
 4 : (01,00,02,01) OK     OK     DAM   0x04fc

 # : (C ,H ,R ,N ) ID-CRC DT-CRC AM    MFM-POS
 5 : (01,00,0d,01) OK     OK     DAM   0x0671
 ```

```sh
python bs_inspect.py -i gutchan_bank.raw -t 0 --id_dump
```

```
** Floppy data capture shield - bit stream data inspect tool
** TRACK  0
 # : (C ,H ,R ,N ) ID-CRC CRC-val
 1 : (00,00,01,01) OK     0x009f
 2 : (00,00,02,01) OK     0x0211
 3 : (00,00,03,01) OK     0x0383
 4 : (00,00,04,01) OK     0x04f5
 5 : (00,00,05,01) OK     0x0667
 6 : (00,00,06,01) OK     0x07d9
 7 : (00,00,07,01) OK     0x094b
 8 : (00,00,08,01) OK     0x0abd
 9 : (00,00,09,01) OK     0x0c2f
10 : (00,00,0a,01) OK     0x0da1
11 : (00,00,0b,01) OK     0x0f13
12 : (00,00,0c,01) OK     0x1085
13 : (00,00,0d,01) OK     0x11f7
14 : (00,00,0e,01) OK     0x136a
15 : (00,00,0f,01) OK     0x14dc
16 : (00,00,10,01) OK     0x164e
17 : (00,00,01,01) OK     0x1962
18 : (00,00,02,01) OK     0x1ad4
19 : (00,00,03,01) OK     0x1c46
```

```sh
python bs_inspect.py -i gutchan_bank.raw -t 0 --id_dump --abort_index
```
`--abort_index` or `--abort_id`

```
python bs_inspect.py -i gutchan_bank.raw -t (0,3) --read_sectors --abort_index
```

```
** Floppy data capture shield - bit stream data inspect tool
** TRACK  0
 # : (C ,H ,R ,N ) ID-CRC CRC-val
 1 : (00,00,01,01) OK     0x009f
 2 : (00,00,02,01) OK     0x0211
 3 : (00,00,03,01) OK     0x0383
 4 : (00,00,04,01) OK     0x04f5
 5 : (00,00,05,01) OK     0x0667
 6 : (00,00,06,01) OK     0x07d9
 7 : (00,00,07,01) OK     0x094b
 8 : (00,00,08,01) OK     0x0abd
 9 : (00,00,09,01) OK     0x0c2f
10 : (00,00,0a,01) OK     0x0da1
11 : (00,00,0b,01) OK     0x0f13
12 : (00,00,0c,01) OK     0x1085
13 : (00,00,0d,01) OK     0x11f7
14 : (00,00,0e,01) OK     0x136a
15 : (00,00,0f,01) OK     0x14dc
16 : (00,00,10,01) OK     0x164e
```

```sh
python bs_inspect.py -i gutchan_bank.raw -t 0 --read_sectors
```
```
** Floppy data capture shield - bit stream data inspect tool
** TRACK  0
 # : (C ,H ,R ,N ) ID-CRC DT-CRC AM    MFM-POS
 1 : (00,00,01,01) OK     OK     DAM   0x009f
 2 : (00,00,02,01) OK     OK     DAM   0x0211
 3 : (00,00,03,01) OK     OK     DAM   0x0383
 4 : (00,00,04,01) OK     OK     DAM   0x04f5
 5 : (00,00,05,01) OK     OK     DAM   0x0667
 6 : (00,00,06,01) OK     OK     DAM   0x07d9
 7 : (00,00,07,01) OK     OK     DAM   0x094b
 8 : (00,00,08,01) OK     OK     DAM   0x0abd
 9 : (00,00,09,01) OK     OK     DAM   0x0c2f
10 : (00,00,0a,01) OK     OK     DAM   0x0da1
11 : (00,00,0b,01) OK     OK     DAM   0x0f13
12 : (00,00,0c,01) OK     OK     DAM   0x1085
13 : (00,00,0d,01) OK     OK     DAM   0x11f7
14 : (00,00,0e,01) OK     OK     DAM   0x136a
15 : (00,00,0f,01) OK     OK     DAM   0x14dc
16 : (00,00,10,01) OK     OK     DAM   0x164e
17 : (00,00,01,01) OK     OK     DAM   0x1962
18 : (00,00,02,01) OK     OK     DAM   0x1ad4
19 : (00,00,03,01) OK     OK     DAM   0x1c46
OK=19, Error=0
```

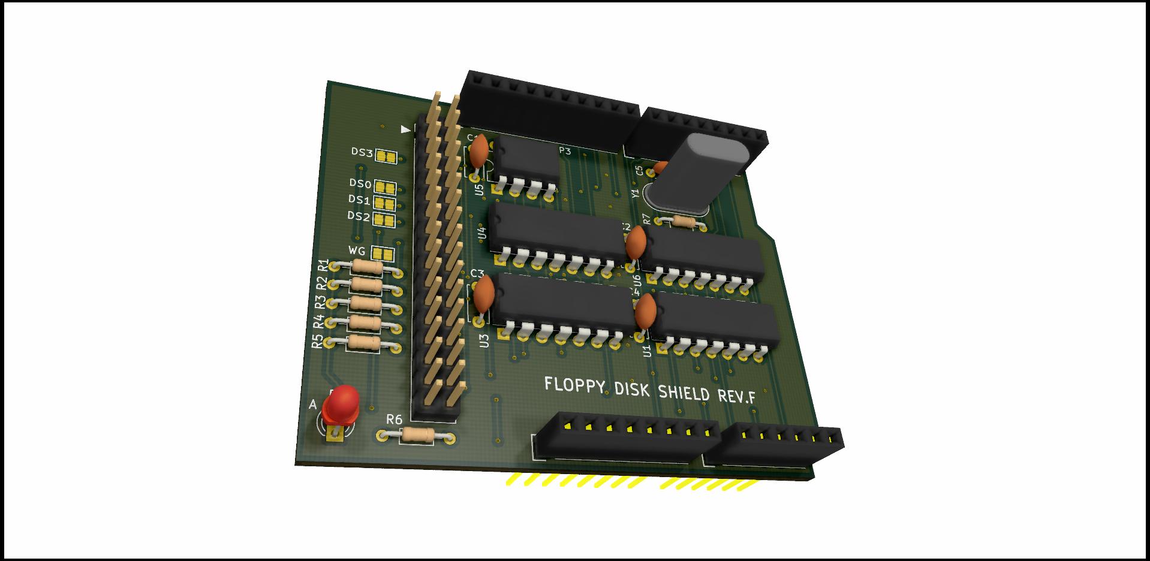
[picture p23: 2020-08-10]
kicad/fdshield-dip/fdshield/fdshield.jpg

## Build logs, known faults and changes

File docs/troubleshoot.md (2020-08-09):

troubleshoot.md

### Read overlap too  much
The 1st sec
1% overlap
```sh
N:\work\fdcapture>python bs_inspect.py -i yd580\princess-quest.log --read_sectors -t 0
** Floppy data capture shield - bit stream data inspect tool
** TRACK  0
 # : (C ,H ,R ,N ) ID-CRC DT-CRC AM    MFM-POS
 1 : (00,00,01,01) OK     OK     DAM   0x002e
 2 : (00,00,02,01) OK     OK     DAM   0x01a5
 3 : (00,00,03,01) OK     OK     DAM   0x031a
 4 : (00,00,04,01) OK     OK     DAM   0x048f
 5 : (00,00,05,01) OK     OK     DAM   0x0604
 6 : (00,00,06,01) OK     OK     DAM   0x0779
 7 : (00,00,07,01) OK     OK     DAM   0x08ef
 8 : (00,00,08,01) OK     OK     DAM   0x0a65
 9 : (00,00,09,01) OK     OK     DAM   0x0bda
10 : (00,00,0a,01) OK     OK     DAM   0x0d4f
11 : (00,00,0b,01) OK     OK     DAM   0x0ec4
12 : (00,00,0c,01) OK     OK     DAM   0x1039
13 : (00,00,0d,01) OK     OK     DAM   0x11ae
14 : (00,00,0e,01) OK     OK     DAM   0x1324
15 : (00,00,0f,01) OK     OK     DAM   0x1499
16 : (00,00,10,01) OK     OK     DAM   0x160f
17 : (00,00,01,01) OK     ERR    DAM   0x18c6
OK=16, Error=1
```

2% overlap
```sh
N:\work\fdcapture>python bs_inspect.py -i yd580\princess-quest.log -t 0 --id_dump
** Floppy data capture shield - bit stream data inspect tool
** TRACK  0
 # : (C ,H ,R ,N ) ID-CRC AM    MFM-POS
 1 : (00,00,01,01) OK     DAM   0x002e
 2 : (00,00,02,01) OK     DAM   0x01a5
 3 : (00,00,03,01) OK     DAM   0x031a
 4 : (00,00,04,01) OK     DAM   0x048f
 5 : (00,00,05,01) OK     DAM   0x0604
 6 : (00,00,06,01) OK     DAM   0x0779
 7 : (00,00,07,01) OK     DAM   0x08ef
 8 : (00,00,08,01) OK     DAM   0x0a65
 9 : (00,00,09,01) OK     DAM   0x0bda
10 : (00,00,0a,01) OK     DAM   0x0d4f
11 : (00,00,0b,01) OK     DAM   0x0ec4
12 : (00,00,0c,01) OK     DAM   0x1039
13 : (00,00,0d,01) OK     DAM   0x11ae
14 : (00,00,0e,01) OK     DAM   0x1324
15 : (00,00,0f,01) OK     DAM   0x1499
16 : (00,00,10,01) OK     DAM   0x160f
```

```sh
N:\work\fdcapture>python bs_inspect.py -i fd55gfr\pascal-master.log --read_sectors -t 71 --high_gain=0.3
** Floppy data capture shield - bit stream data inspect tool
** TRACK  71
 # : (C ,H ,R ,N ) ID-CRC DT-CRC AM    MFM-POS
 1 : (23,01,01,01) OK     OK     DAM   0x00a0
 2 : (23,01,02,01) OK     OK     DAM   0x0218
 3 : (23,01,03,01) OK     OK     DAM   0x0390
 4 : (23,01,04,01) OK     OK     DAM   0x0509
 5 : (23,01,05,01) OK     OK     DAM   0x0683
 6 : (23,01,06,01) OK     OK     DAM   0x07fb
 7 : (23,01,07,01) OK     OK     DAM   0x0973
 8 : (23,01,08,01) OK     OK     DAM   0x0aeb
 9 : (23,01,09,01) OK     OK     DAM   0x0c63
10 : (23,01,0a,01) OK     OK     DAM   0x0dda
11 : (23,01,0b,01) OK     OK     DAM   0x0f52
12 : (23,01,0c,01) OK     OK     DAM   0x10cb
13 : (23,01,0d,01) OK     OK     DAM   0x1243
14 : (23,01,0e,01) OK     OK     DAM   0x13bb
15 : (23,01,0f,01) OK     OK     DAM   0x1533
16 : (23,01,10,01) OK     ERR    DAM   0x16ad
OK=15, Error=1
```

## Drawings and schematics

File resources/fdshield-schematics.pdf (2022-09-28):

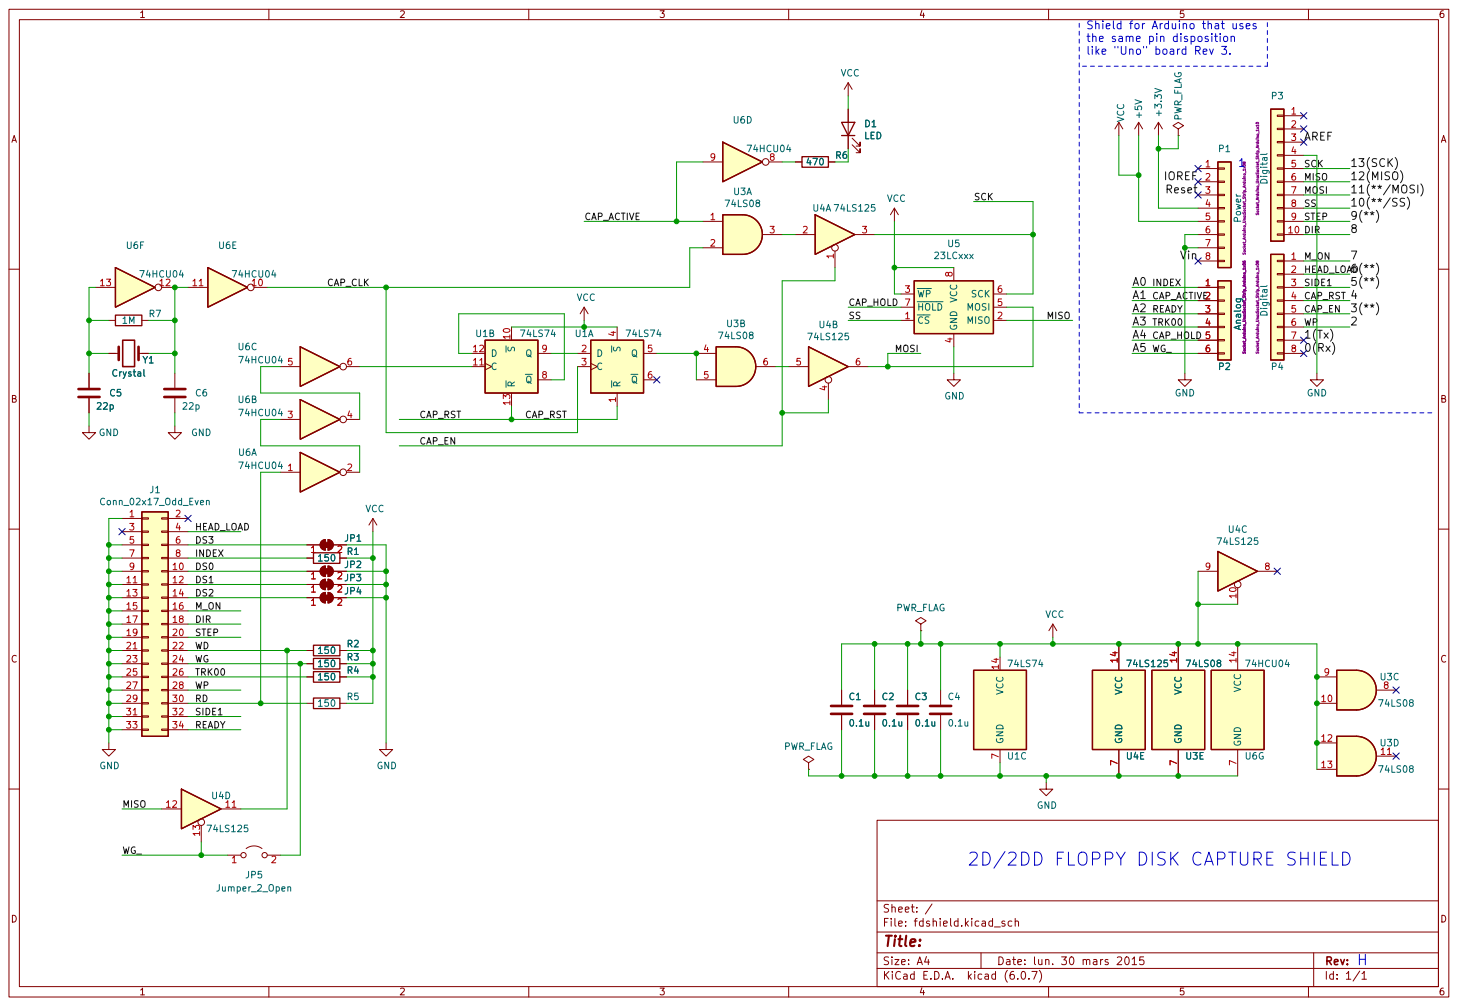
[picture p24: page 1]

like "Uno" board Rev 3. 2D/2DD FLOPPY DISK CAPTURE SHIELD

Shield for Arduino that uses
the same pin disposition

4 MOSI 5 SCK 6 ~{HOLD} 7 VCC

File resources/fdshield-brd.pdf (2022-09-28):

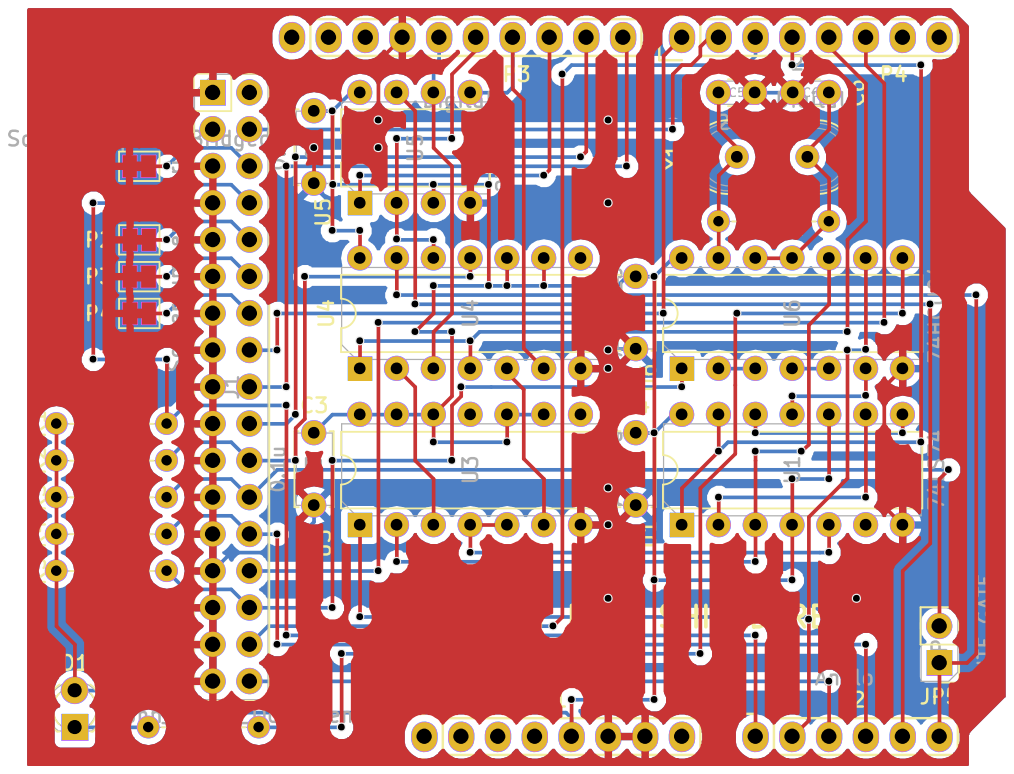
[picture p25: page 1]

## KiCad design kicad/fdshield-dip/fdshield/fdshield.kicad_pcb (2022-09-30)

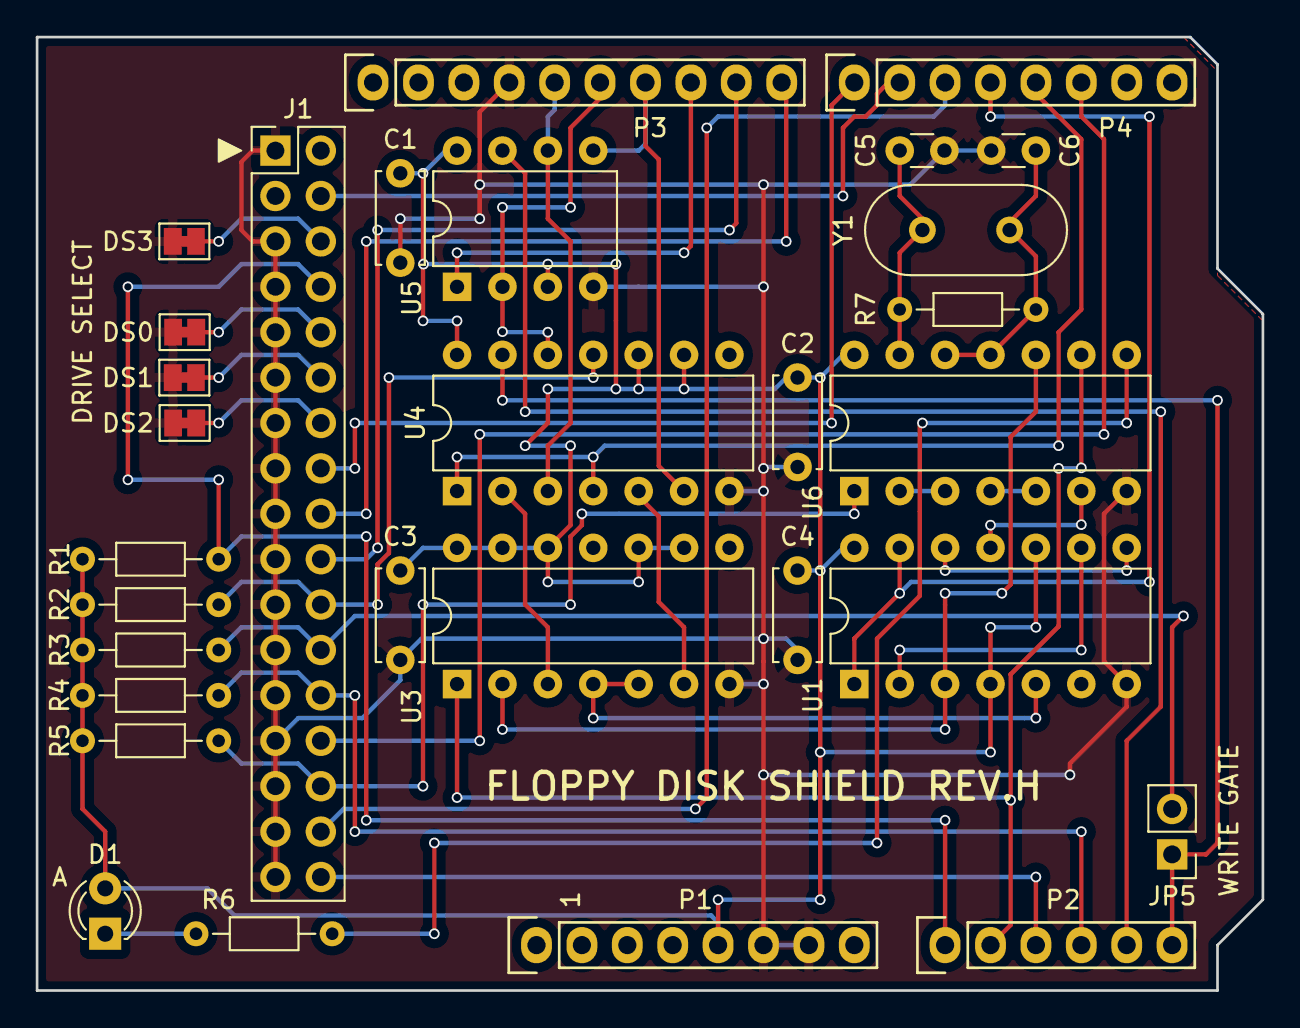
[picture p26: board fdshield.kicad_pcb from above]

Board: 2 copper layers, 68.6 x 53.3 mm, 30 parts (0 on the bottom side), 40 nets.

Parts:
C1, C2, C3, C4: 0.1u; C_Disc_D5.0mm_W2.5mm_P5.00mm
C5, C6: 22p; C_Disc_D3.0mm_W1.6mm_P2.50mm
D1: LED; LED_D3.0mm
DS0, DS1, DS2, DS3: SolderJumper_2_Bridged; SolderJumper-2_P1.3mm_Bridged_Pad1.0x1.5mm
J1: Conn_02x17_Odd_Even; PinHeader_2x17_P2.54mm_Vertical
JP5: WRITE GATE; PinHeader_1x02_P2.54mm_Vertical
P1: Power; Socket_Strip_Arduino_1x08
P2: Analog; Socket_Strip_Arduino_1x06
P3: Digital; Socket_Strip_Arduino_1x10
P4: Digital; Socket_Strip_Arduino_1x08
R1, R2, R3, R4, R5: 150; R_Axial_DIN0204_L3.6mm_D1.6mm_P7.62mm_Horizontal
R6: 470; R_Axial_DIN0204_L3.6mm_D1.6mm_P7.62mm_Horizontal
R7: 1M; R_Axial_DIN0204_L3.6mm_D1.6mm_P7.62mm_Horizontal
U1: 74LS74; DIP-14_W7.62mm
U3: 74LS08; DIP-14_W7.62mm
U4: 74LS125; DIP-14_W7.62mm
U5: 23LCxxx; DIP-8_W7.62mm
U6: 74HCU04; DIP-14_W7.62mm
Y1: Crystal; Crystal_HC49-U_Vertical

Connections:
+5V: C1.1, C2.1, C3.1, C4.1, D1.2 (A), P1.5, R1.1, R2.1, R3.1, R4.1, R5.1, U1.4 (~S), U1.10 (~S), U1.14 (VCC), U3.9, U3.10, U3.12, U3.13, U3.14 (VCC), U4.9, U4.10, U4.14 (VCC), U5.3 (~WP), U5.8 (VCC), U6.14 (VCC)
/2: J1.28, P4.6
/3(**): P4.5, U4.1, U4.4
/4: P4.4, U1.1 (~R), U1.13 (~R)
/5(**): J1.32, P4.3
/6(**): J1.4, P4.2
/7: J1.16, P4.1
/8: J1.18, P3.10
/9(**): J1.20, P3.9
/10(**/SS): P3.8, U5.1 (~CS)
/11(**/MOSI): P3.7, U4.6, U5.5 (MOSI)
/12(MISO): P3.6, U4.12, U5.2 (MISO)
/13(SCK): P3.5, U4.3, U5.6 (SCK)
/A0: J1.8, P2.1, R1.2
/A1: P2.2, U3.1, U6.9
/A2: J1.34, P2.3
/A3: J1.26, P2.4, R4.2
/A4: P2.5, U5.7 (~HOLD)
/A5: JP5.1 (A), P2.6, U4.13
/CAP_CLK: U1.3 (C), U3.2, U6.10
/DS0: DS0.1 (A), J1.10
/DS1: DS1.1 (A), J1.12
/DS2: DS2.1 (A), J1.14
/DS3: DS3.1 (A), J1.6
/RD: J1.30, R5.2, U6.1
/WD: J1.22, R2.2, U4.11
/WG: J1.24, JP5.2 (B), R3.2
GND: C1.2, C2.2, C3.2, C4.2, C5.2, C6.2, DS0.2 (B), DS1.2 (B), DS2.2 (B), DS3.2 (B), J1.1, J1.5, J1.7, J1.9, J1.11, J1.13, J1.15, J1.17, J1.19, J1.21, J1.23, J1.25, J1.27, J1.29, J1.31, J1.33, P1.6, P1.7, P3.4, U1.7 (GND), U3.7 (GND), U4.7 (GND), U5.4 (GND), U6.7 (GND)
unnamed: C5.1, R7.2, U6.13, Y1.1
unnamed: C6.1, R7.1, U6.11, U6.12, Y1.2
unnamed: D1.1 (K), R6.1
unnamed: R6.2, U6.8
unnamed: U1.2 (D), U1.9 (Q)
unnamed: U1.5 (Q), U3.4, U3.5
unnamed: U1.11 (C), U6.6
unnamed: U1.8 (~Q), U1.12 (D)
unnamed: U3.3, U4.2
unnamed: U3.6, U4.5
unnamed: U6.2, U6.3
unnamed: U6.4, U6.5

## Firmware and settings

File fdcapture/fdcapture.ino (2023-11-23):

// 2D/2DD Floppy disk capture shield control software

#include <stdio.h>
#include <limits.h>

#include <SPI.h>
#include <avr/pgmspace.h>

#include "fdd.h"
#include "spi_memory.h"
#include "fdcaptureshield.h"

#if !defined(__AVR_ATmega328P__)
#error This program can only run on Arduino Uno.
#endif

uint8_t cmdBuf[cmdBufSize+1];

uint16_t g_spin_tick;          // FDD spin time (Timer 1 tick count @ 250KHz)
uint32_t g_calibrated_clock;   // Calibrated timer1 clock

// GPIO mapping
#define FD_WG         (A5)   // Write gate signal !!DANGER!!
#define SPIMEMORY_HOLD  (A4)
#define FD_TRK00      (A3)
#define FD_READY      (A2)
#define CAP_ACTIVE    (A1)
#define FD_INDEX      (A0)
#define SPI_SCK       (13)
#define SPI_MISO      (12)
#define SPI_MOSI      (11)
#define SPI_SS        (10)
#define FD_STEP       (9)
#define FD_DIR        (8)
#define FD_MOTOR      (7)
#define FD_HEAD_LOAD  (6)
#define FD_SIDE1      (5)
#define CAP_RST       (4)
#define CAP_EN        (3)
#define FD_WP         (2)  // WP == LOW

void debug_blink(void)
{
  while(true) {
    digitalWrite(CAP_ACTIVE, HIGH);
    delay(300);
    digitalWrite(CAP_ACTIVE, LOW);
    delay(300);
  }
}

// Objects
FDD fdd;
SPIMEMORY spimemory;
FDCaptureShield FDCap;
#if SPI_MEMORY_TYPE == SPI_MEMORY_CY15B104Q
const unsigned long TRACK_CAPACITY_BYTE   = ((1024L*1024L*4L)/8L); // 1Mbit SRAM full capacity
#elif SPI_MEMORY_TYPE == SPI_MEMORY_23LC1024
const unsigned long TRACK_CAPACITY_BYTE   = ((1024L*1024L*1L)/8L); // 1Mbit SRAM full capacity
#endif

void dumpTrack_encode(unsigned long bytes = 0UL) {

  spimemory.beginRead();

  if (bytes == 0) bytes = TRACK_CAPACITY_BYTE;

  int prev = 0;
  int count = 1;
  int b;
  int chr_count = 0;
  byte out;
  for (unsigned long i = 0; i < bytes; i++) {
    int dt = spimemory.transfer(0);
    const uint8_t encode_base = ' ';
    const uint8_t max_length = 'z'-encode_base;
    const uint8_t extend_char = '{';
    for (int p = 0; p < 8; p++) {
      b = (dt & 0x80u) ? 1 : 0;
      dt <<= 1;
      if (b == prev) {    // no pulse
        if(++count >= max_length) {
          if (chr_count == 0) {
            Serial.write('~');    // Start line code
          }
          Serial.write(extend_char);        // state extend character (extend pulse-to-pulse period without pulse)
          count -= max_length;
          chr_count++;
          if (chr_count == 99) {
            chr_count = 0;
            Serial.println("");
          }
        }
      } else {            // pulse
        out = count + encode_base;
        if (chr_count == 0) {
          Serial.write('~');    // Start line code
        }
        Serial.write(out);
        count = 1;
        chr_count++;
        if (chr_count == 99) {
          chr_count = 0;
          Serial.println("");
        }
      }
      prev = b;
    }
  }
  spimemory.endAccess();
  Serial.println(F(""));
}


// =================================================================


// Read single track
void trackRead(uint16_t capture_tick_count) {
  spimemory.beginWrite();
  spimemory.hold(LOW);
  spimemory.disconnect();                              // Disconnect SPI SRAM from Arduino

  noInterrupts();
  uint8_t TCCR1A_bkup = TCCR1A;
  uint8_t TCCR1B_bkup = TCCR1B;
  TCCR1A &= 0xfc;            // Timer1, 16b timer, WGM11,WGM10 = 0,0 = Normal mode. default = 0,1 = PWM, Phase correct, 8-bit
  TCCR1B  = 0x03;            // Timer1, WGM13,WGM12 = 0,0 / CS12,CS11,CS10 = 0,1,1 = clkIO/64

  MACRO_WAIT_INDEX();                                // wait for next index pulse
  TCNT1 = 0;                                         // Reset timer counter

  // Start captuering
  MACRO_DISABLE_SPI_HOLD();
  MACRO_FDCAP_CONNECT();

  while(TCNT1 < capture_tick_count) /* NOP */ ;

  // Stop capturing
  MACRO_DISABLE_SAMPLING_CLOCK();

  TCCR1A = TCCR1A_bkup;
  TCCR1B = TCCR1B_bkup;
  interrupts();

  FDCap.disconnect();
  spimemory.connect();
  spimemory.endAccess();
}

// Read tracks  (track # = 0-79 (,83))
void read_tracks(int start_track, int end_track, int read_overlap) {
  fdd.track00();

  uint32_t sampling_clock;
#if 0
  //Serial.print("**SAMPLING_RATE 4000000\n");    // 4MHz is the default sampling rate of the Arduino FD shidld.
  sampling_clock = 4e6;
#else
  Serial.print("**SAMPLING_RATE 8000000\n");    // 4MHz is the default sampling rate of the Arduino FD shidld.
  sampling_clock = 8e6;
#endif

  uint32_t capture_tick_count = ((100 + (uint32_t)read_overlap) * (uint32_t)g_spin_tick) / 100;
  if(capture_tick_count > 0xffffu) capture_tick_count = 0xffffu;
  uint32_t capture_capacity_byte = ((sampling_clock / g_calibrated_clock) * capture_tick_count) / 8;

  Serial.print(";CAPACITY[bytes]:");
  Serial.println(capture_capacity_byte);

  size_t curr_trk = 0;
  for (size_t trk = start_track; trk <= end_track; trk++) {
    size_t fdd_track = trk / 2;
    size_t fdd_side  = trk % 2;
    fdd.seek(curr_trk, fdd_track);
    curr_trk = fdd_track;

    fdd.side(fdd_side);
    spimemory.clear();

    Serial.print(F("**TRACK_READ "));
    Serial.print(fdd_track);
    Serial.print(F(" "));
    Serial.println(fdd_side);

    trackRead(capture_tick_count);

    dumpTrack_encode(capture_capacity_byte);    // Dump captured data
    //dumpTrack_encode(TRACK_CAPACITY_BYTE);    // SPI SRAM full dump
    Serial.println(F("**TRACK_END"));
  }
}


// =================================================================


uint8_t count_space_chars(uint8_t *str) {
  uint8_t count = 0;
  uint8_t prev = '\0';
  while(*str != '\0') {
    if(*str == ' ' && prev != ' ') {
      count++;
    }
    prev = *str++;
    if(count > 10) break;   // safeguard
  }
  return count;
}

// Write single track
void trackWrite(uint32_t bits_to_write, uint16_t time_out_tick=0 /* 1tick=250KHz */) {

#if 0
  spimemory.beginRead();
  // SPI SRAM contents dump - debug purpose
  for(int i=0; i<0x2000; i++) {
    uint8_t dt = spimemory.transfer(0);
    if(dt < 0x10) Serial.print("0");
    Serial.print(dt, HEX);
    //if(i % 32==31) Serial.print("\n");
  }
  Serial.println();
  spimemory.endAccess();
#endif

  spimemory.beginRead();
  spimemory.hold(LOW);
  spimemory.disconnect();              // Disconnect SPI SRAM from Arduino

  noInterrupts();
  uint8_t TCCR1A_bkup = TCCR1A;
  uint8_t TCCR1B_bkup = TCCR1B;
  TCCR1A &= 0xfc;            // Timer1, 16b timer, WGM11,WGM10 = 0,0 = Normal mode. default = 0,1 = PWM, Phase correct, 8-bit
  TCCR1B  = 0x03;            // Timer1, WGM13,WGM12 = 0,0 / CS12,CS11,CS10 = 0,1,1 = clkIO/64

  MACRO_FDCAP_CONNECT_AND_STANDBY();          // Enable fd-shield, keep SCK line low.

  MACRO_WAIT_INDEX();
  TCNT1 = 0;                                  // Reset timer counter

  // Start writing
  MACRO_ENABLE_WG();                          // Enable WG
  MACRO_DISABLE_SPI_HOLD();
  MACRO_ENABLE_SAMPLING_CLOCK();              // Start supplying 4MHz clock to SCK

  if(time_out_tick == 0) {
    MACRO_WAIT_INDEX();                       // wait for next index pulse
  } else {
    while(TCNT1 < time_out_tick) /* NOP */ ;  // Wait until specified time passed
  }
  MACRO_DISABLE_WG();                         // Disable WG right after the next index hole detection

  TCCR1A = TCCR1A_bkup;                       // Restore timer1 setting
  TCCR1B = TCCR1B_bkup;
  interrupts();

  digitalWrite(SPI_SS, HIGH);
  FDCap.disconnect();
  spimemory.connect();
  spimemory.endAccess();
}

// Write tracks
// normalize_mode : 0=no normalize, 1=perform normalize
void write_tracks(int normalize_mode) {
  const uint8_t encode_base = ' ';
  const uint8_t max_length = 'z'-encode_base;
  const uint8_t extend_char = '{';
  const uint8_t bit_cell      = 8;
  const uint8_t bit_cell_half = bit_cell / 2;

  fdd.track00();
  int curr_trk = 0;
  int trk, sid;
  unsigned int write_bits = 0;   // number of bits to write
  uint8_t test = 0;

  uint8_t mode = 0;     // Command mode
  uint8_t dist = 0;    // data pulse distance
  uint8_t bit_dt = 0;
  uint64_t total_bits = 0L;
  bool overflow_warning = false;

  // Measure spindle spin time (1 tick = 250KHz)
  uint32_t spin_time_tick = 0;
  for(int i = 0; i < 4; i++) {
    spin_time_tick += fdd.measure_rpm_tick();
  }
  spin_time_tick /= 4;
  Serial.print("#SPIN_TIME_TICK $");
  Serial.println(spin_time_tick, HEX);

  Serial.println(F("++READY"));
  while(true) {
    readLine(cmdBuf, cmdBufSize);
    uint8_t cmdLen = strlen(cmdBuf);
    if(cmdLen > cmdBufSize) cmdLen = cmdBufSize;
    if(cmdBuf[0] == '*' && cmdBuf[1] == '*') {          // CMD
      if(cmdBuf[2] == 'T' && cmdBuf[8] == 'R') {        // **TRACK_READ 0 0
        mode = 1;   // Read track data mode
        if(count_space_chars(cmdBuf) == 3) {
          sscanf(cmdBuf+12, "%d %d %d", &trk, &sid, &write_bits); // write will finish after (write_bits) written
        } else {
          sscanf(cmdBuf+12, "%d %d", &trk, &sid);
          write_bits = 0;                               // Write will finish on 2nd index hole detection
        }
        FDCap.disconnect();                             // CAP_ACTIVATE=LOW, CAP_EN=HIGH
        spimemory.connect();                              // Activate SPI_SS, SPI_SCK, SPI_MOSI, SPI_MISO
        fdd.seek(curr_trk, trk);
        fdd.side(sid);
        curr_trk = trk;
        total_bits = 0;
        overflow_warning = false;
        spimemory.fill(0xff);
        spimemory.beginWrite();
      } else if(cmdBuf[2] == 'T' && cmdBuf[8] == 'E') { // **TRACK_END
        mode = 0;   // Command mode
        spimemory.flush();
        spimemory.endAccess();
        uint32_t bits = spimemory.getLength();
        trackWrite(bits, write_bits);
        if(write_bits > 0) {
          Serial.print(F("\n#$"));
          Serial.print(write_bits, HEX);
          Serial.println(F(" written."));
        }
      } else if(cmdBuf[2] == 'M' && cmdBuf[8] == 'T') { // **MEDIA_TYPE
      } else if(cmdBuf[2] == 'S' && cmdBuf[7] == 'S') { // **SPIN_SPD 0.199
      } else if(cmdBuf[2] == 'O' && cmdBuf[6] == 'L') { // **OVERLAP 0
      } else if(cmdBuf[2] == 'C' && cmdBuf[7] == 'E') { // **COMPLETED
        break;
      }
    }
    if(mode == 1) {
      if(cmdBuf[0] == '~') {                // Pulse data line
        for(uint8_t i = 1; i < cmdLen; i++) {   // skip '~' on the top of the line
          if(cmdBuf[i] < ' ') continue;
          dist = cmdBuf[i] - encode_base;
          if(dist >= 1) {
            if(normalize_mode == 1) {
              //dist = (dist + bit_cell_half) & (~(bit_cell-1));
              dist = (dist+4) & 0b11111000u;      // assuming the bit cell width is 8 (2D/2DD).
              //dist = (dist+2) & 0b11111100u;      // assuming the bit cell width is 4 (2HD).
            }
            if(total_bits + dist > spimemory.SPIMEMORY_CAPACITY_BYTE * 8) {   // SPI SRAM overflow
              if(overflow_warning == false) {
                Serial.println("\n!!SPI-SRAM OVERFLOWED");
                overflow_warning = true;
              }
              dist = 0;
              continue;
            }
            total_bits += dist;
            if(cmdBuf[i] != extend_char && dist <= max_length) {
              for(uint8_t b = 0; b < dist - 1; b++) {
                spimemory.writeBit(1);
              }
              spimemory.writeBit(bit_dt);         // make a pulse
            } else {
              for(uint8_t b = 0; b < max_length; b++) {
                spimemory.writeBit(1);            // don't make pulse
              }
            }
          }
        }
      }
    }
    Serial.println("++ACK");
  };
}

// =================================================================

// Testing SPI SRAM
void test_spi_sram(void) {
  const uint32_t spimemory_CAPACITY_BYTE = 2 * 65536UL; // 1Mbit SRAM (bytes)

  spimemory.connect();

  Serial.println(F("Testing SPI SRAM..."));
  spimemory.beginWrite();
  for(uint64_t adr = 0; adr < spimemory_CAPACITY_BYTE; adr++) {
    for(uint8_t bit = 0x80u; bit > 0; bit >>= 1) {
      spimemory.writeBit((adr & bit) ? 1 : 0);
    }
  }
  spimemory.flush();
  spimemory.endAccess();

  uint32_t bits = spimemory.getLength();
  Serial.println(F("Write completed."));
  Serial.print(bits);
  Serial.println(F(" bits written."));

#if 0
  // error injection
  spimemory.beginWrite();
  spimemory.transfer(0x08);
  spimemory.endAccess();
#endif

  spimemory.beginRead();
  for(uint64_t adr = 0; adr < spimemory_CAPACITY_BYTE; adr++) {
    uint8_t dt = spimemory.transfer(0);
    if(dt != (adr & 0xffu)) {
      Serial.println(F("Compare error ("));
      Serial.print((uint8_t)adr, HEX);
      Serial.print(F(") : C="));
      Serial.print((uint8_t)(adr & 0xffu), HEX);
      Serial.print(F(" - "));
      Serial.println(dt, HEX);
    }
  }
  spimemory.endAccess();
  Serial.println(F("Test completed."));
}


// =================================================================

// Calibrate motor speed
void revolution_calibration(void) {
  float spin;
  while(true) {
    spin = fdd.measure_rpm();
    Serial.println(spin * 1000, DEC); // ms
  }
}

// Measure FDD spindle speed (measure time for 5 spins)
void report_spindle_speed(void) {
    float spin = 0.f;
    uint32_t spin_tick = 0;
    for(int i=0; i<5; i++) {
      spin_tick += fdd.measure_rpm_tick();
    }
    spin_tick /= 5;
    spin = (double)spin_tick / (double)g_calibrated_clock;
    Serial.print(F("**SPIN_SPD "));
    Serial.println(spin, 8);
    g_spin_tick = spin_tick;    // 250KHz tick, 200ms = 50,000 count
}

// =================================================================


uint8_t readLine(uint8_t buf[], const uint8_t buf_size) {
  uint8_t ch;
  uint8_t pos = 0;
  buf[0] = '\0';
  while(pos < buf_size) {
    buf[pos] = '\0';
    while(Serial.available()==0);
    ch = Serial.read();
    if(ch == '\n') break;
    if(ch >= ' ' && ch <= 0x7e) {   // stores only readable characters
      buf[pos++] = ch;
    }
  }
  return pos;
}


void setup() {
  // Make sure that the FD_capture board doesn't drive MOSI and SCK lines
  FDCap.init();
  spimemory.init();

  Serial.begin(115200);

  fdd.init();                                     // Motor on, Head load on
  delay(200);

  spimemory.clear();

  Serial.println("");
  Serial.println(F("**FLOPPY DISK SHIELD FOR ARDUINO"));
  g_calibrated_clock = 250e3;                     // Default clock for timer1
}

// Command format
// "+R strack etrack mode overlap"
// "+V"
void loop() {
  char cmd;

  Serial.println(F("++CMD"));
  readLine(cmdBuf, cmdBufSize);
  if(cmdBuf[0] != '+') {      // Command line must start with '+'.
    Serial.println(F("++ERR"));
    return;
  }
  cmd = toupper(cmdBuf[1]);

  if(cmd == 'R') {
    fdd.head(true);
    fdd.motor(true);
    enum FDD::ENUM_DRV_MODE media_mode = FDD::ENUM_DRV_MODE::mode_2d;
    int start_track, end_track;
    int read_overlap;   // track read overlap (%)
    sscanf(cmdBuf, "+R %d %d %d %d", &start_track, &end_track, &media_mode, &read_overlap);
    fdd.set_media_type(media_mode);
    Serial.println(F("**START"));

    // Detect FDD type (2D/2DD)
    fdd.detect_drive_type();
    fdd.track00();

    report_spindle_speed();

    uint32_t sampling_tick_count = ((100 + (uint32_t)read_overlap) * (uint32_t)g_spin_tick) / 100;
    if(sampling_tick_count > 0xffffu) {
      read_overlap = (int)(((double)0x10000 / (double)g_spin_tick) * 100.f - 100.f);
      Serial.print(F("##READ_OVERLAP IS LIMITED TO "));
      Serial.print(read_overlap);
      Serial.println(F("% BECAUSE THE AMOUNT OF CAPTURE DATA EXCEEDS THE MAX SPI-SRAM CAPACITY."));
    }
    Serial.print(F("**OVERLAP "));
    Serial.println(read_overlap);

    // Read all tracks
    read_tracks(start_track, end_track, read_overlap);

    Serial.println(F("**COMPLETED"));
  }
  // WRITE command needs to be 'WR' not 'W'.
  if(cmd == 'W') {
    fdd.head(true);
    fdd.motor(true);
    if(cmdBuf[2] != 'R') return;
    if(fdd.isWriteProtected() == true) {
      Serial.println(F("++WRITE_PROTECTED"));
    } else {
      uint8_t cmd;
      int normalize_flag;
      sscanf(cmdBuf, "+WR %d", &normalize_flag);
      // Detect FDD type (2D/2DD)
      fdd.detect_drive_type();
      enum FDD::ENUM_DRV_MODE media_mode = FDD::ENUM_DRV_MODE::mode_2d;
      fdd.set_media_type(media_mode);
      if(normalize_flag) {
        Serial.println(F("**Bit pulse timing normalizer activated."));
      }
      write_tracks(normalize_flag);
    }
  }
  if(cmd == 'V') {
    fdd.head(true);
    fdd.motor(true);
    Serial.println(F("**Revolution calibration mode"));
    revolution_calibration();
  }
  if(cmd == 'C') {
    fdd.head(true);
    fdd.motor(true);
    uint16_t tick;
    uint32_t ttl_tick = 0;
    const uint8_t niter = 5;
    for(int i=0; i < niter; i++) {
      tick = fdd.measure_rpm_tick();
      ttl_tick += tick;
    }
    tick = ttl_tick / niter;
    Serial.print(F("++SPIN_TICK "));
    Serial.println(tick, DEC); // ms
  }
  if(cmd == 'T') {
    test_spi_sram();
  }
  if(cmd == 'S') {    // Set timer clock (for timer 1 calibration)
    unsigned long calibrated_clock;
    sscanf(cmdBuf, "+S %ld", &calibrated_clock);
    g_calibrated_clock = calibrated_clock;
    Serial.print(F("#CALIBRATED CLOCK="));
    Serial.println(g_calibrated_clock);
  }
  if(cmd == 'M') {
    // Measure timer1 clock speed for calibration
    noInterrupts();
    uint8_t TCCR1A_bkup = TCCR1A;
    uint8_t TCCR1B_bkup = TCCR1B;
    TCCR1A = 0x00;                    // Timer1, 16b timer, WGM11,WGM10 = 0,0 = Normal mode. default = 0,1 = PWM, Phase correct, 8-bit
    TCCR1B = 0x03;                    // Timer1, WGM13,WGM12 = 0,0 / CS12,CS11,CS10 = 0,1,1 = clkIO/64

    Serial.print('S');
    Serial.flush();
    for(int i = 0; i < 40; i++) {         // 250KHz * 0x8000 * 40 = 5.24288 sec
      TCNT1 = 0;
      while(TCNT1 < 0x8000) /* nop */ ;   // 250KHz * 0x8000 = 0.131072 sec
    }
    TCCR1A = TCCR1A_bkup;                 // Restore timer1 setting
    TCCR1B = TCCR1B_bkup;
    Serial.print('E');
    Serial.flush();
    interrupts();
  }
  if(cmd == '@') {    // experimental code
    noInterrupts();
    uint8_t TCCR1A_bkup = TCCR1A;
    uint8_t TCCR1B_bkup = TCCR1B;
    //Serial.println(TCCR1A, BIN);
    //Serial.println(TCCR1B, BIN);
#if 0
    uint16_t count;
    while(true) {
      count = fdd.measure_rpm_tick();
      Serial.println(count, HEX);
    }
#endif
#if 1
    TCCR1A = 0x00;                    // Timer1, 16b timer, WGM11,WGM10 = 0,0 = Normal mode. default = 0,1 = PWM, Phase correct, 8-bit
    TCCR1B = 0x03;                    // Timer1, WGM13,WGM12 = 0,0 / CS12,CS11,CS10 = 0,1,1 = clkIO/64
    uint16_t half_period;
    uint32_t calibrated_clock;
    sscanf(cmdBuf, "+@ %ld", &calibrated_clock);
    double target_time = 0.2f;
    half_period = calibrated_clock * target_time;

    for(uint8_t i=0; i<10; i++) {
      PORTC &= ~0x20;                 // WG_
      TCNT1 = 0;                      // Reset timer counter
      while(TCNT1 < half_period) /* NOP */ ;

      PORTC |= 0x20;                  // WG_
      TCNT1 = 0;                      // Reset timer counter
      while(TCNT1 < half_period) /* NOP */ ;
    }
#endif
#if 0
  // Oscillation output by compare match -> OC1A, OC1B pins
  TCCR1A = 0x50;  // OC1A/OC1B toggle on compare match
  TCCR1B = 0x03 + 0x08 /* WGM13,12 = 0,1 = CTC */;
  OCR1A = 0xffff;

  while(1);
#endif

    TCCR1A = TCCR1A_bkup;             // Restore timer1 setting
    TCCR1B = TCCR1B_bkup;
    interrupts();
  }
  //fdd.head(false);
  //fdd.motor(false);
}

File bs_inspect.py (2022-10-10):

# bitstream inspector

import sys
import argparse
import cv2
import numpy as np

import matplotlib.pyplot as plt

from floppylib.bitstream import bitstream
from floppylib.dataseparator import data_separator
from floppylib.formatparserIBM import FormatParserIBM
from floppylib.d77image import d77_image
from floppylib.crc import CCITT_CRC

def putTextVert(img:np.array, text:str, org, fontFace, fontScale, color, thickness=1, lineType=8, bottomLeftOrigin=False):
    size, base_line = cv2.getTextSize(text, fontFace, fontScale, thickness)
    text_img = np.zeros((size[1] + base_line, size[0], 3), dtype=np.uint8)
    cv2.putText(text_img, text, (0, size[1]), fontFace, fontScale, color, thickness, lineType, bottomLeftOrigin)
    text_img = np.transpose(text_img, (1,0,2))
    text_img = text_img[::-1,:,:]
    x0 = org[0]
    x1 = org[0]+text_img.shape[1]
    y0 = org[1]-text_img.shape[0]
    y1 = org[1]
    if x0 > 0 and x1 < img.shape[1] and y0 > 0 and y1 < img.shape[0]:
        img[y0:y1, x0:x1,:] = text_img


def pause():
    while True:
        key = cv2.waitKey(1)
        if key == ord(' '):
            return
        if key == 27:
            sys.exit(0)


# MFM decoder for bitstream visualizer
class decode_MFM:
    def __init__(self):
        self.data           = 0
        self.read_bit_count = 0   # read bit count
        self.cd_stream      = 0
        self.mode           = 0
        missing_clock_c2 = (0x5224)  #  [0,1,0,1, 0,0,1,0, 0,0,1,0, 0,1,0,0]
        missing_clock_a1 = (0x4489)  #  [0,1,0,0, 0,1,0,0, 1,0,0,0, 1,0,0,1]
        pattern_ff       = (0x5555555555555555)  # for 4 bytes of sync data (unused)
        pattern_00       = (0xaaaaaaaaaaaaaaaa)  # for 4 bytes of sync data
        self.missing_clock = [ missing_clock_c2, missing_clock_a1 ]
        #self.sync_pattern  = [ pattern_ff, pattern_00 ]
        self.sync_pattern  = [ pattern_00 ]

    def decode(self, bit, ds):
        if self.read_bit_count % 2 == 1:
            self.data = (self.data<<1) | bit   # stores only data bits (skip clock bits)
        self.read_bit_count += 1

        self.cd_stream = ((self.cd_stream<<1) | bit) & 0xffffffffffffffff
        if self.mode == 0 and (self.read_bit_count & 1) == 0 and ((self.cd_stream & 0x7fff) in self.missing_clock):  # Ignore MC compare on clock cycle
            data = self.data
            self.data = 0
            self.read_bit_count = 0
            return data, True        # missing clock detected

        if self.mode == 0 and (self.cd_stream in self.sync_pattern):
            ds.switch_gain(1)      # Fast tracking mode to get syncronized with SYNC pattern
            self.read_bit_count &= ~1     # C/D synchronize
        else:
            ds.switch_gain(0)

        if self.read_bit_count >= 16:
            data = self.data
            self.data = 0
            self.read_bit_count = 0
            return data, False       # 8 bit data read completed
        return -1, False             # read data incomplete



# Visualize bitstream timing
def timing_history(bit_stream, spin_spd, args):
    val_max = 24
    ystep = 1
    xstep = 8
    cell = 8
    height = 400
    graph_x_ofst = 8
    writer = cv2.VideoWriter('history.mp4', cv2.VideoWriter_fourcc(*'mp4v'), 240, ((graph_x_ofst+val_max)*xstep, height))

    ds = data_separator(bit_stream, clk_spd=args.clk_spd, spin_spd=spin_spd, high_gain=args.high_gain, low_gain=args.low_gain)
    mfm_decoder = decode_MFM()

    count=0
    img = np.zeros((height, (graph_x_ofst+val_max) * xstep, 3), dtype=np.uint8)
    bit_sts = 0
    draw = 0
    while True:
        bit, pos, advance = ds.get_bit_ex()
        bit_sts |= bit          # accumlate bit status in the same cell
        if advance:
            mfm, mc = mfm_decoder.decode(bit_sts, ds)
            if mfm != -1:
                color = (255,255,255) if mc==False else (0,255,255)
                cv2.putText(img, format(mfm, '02x'), (10, height), cv2.FONT_HERSHEY_PLAIN, 1, color, 1)
            if bit_sts == 1:
                draw = 1
            bit_sts = 0

        if count % 1==0:
            cell_size = ds.vfo.cell_size
            window_start = ds.vfo.window_ofst
            window_end   = ds.vfo.window_ofst + ds.vfo.window_size
            img[:-ystep, :, :] = img[ystep:, :, :]  # scroll up
            img[-ystep:, :, :] = [64,0,0]
            img[-1, int((graph_x_ofst               )*xstep):int((graph_x_ofst + cell_size) *xstep), :] = [0,0,128]
            img[-1, int((graph_x_ofst + window_start)*xstep):int((graph_x_ofst + window_end)*xstep), :] = [255,0,0]
        pos = int((graph_x_ofst + pos)*xstep)
        dataPos = min(pos, img.shape[1]-1)
        if draw == 1:
            img[-1, dataPos:dataPos+xstep, : ] = [ 255, 255, 255]                # data point
            draw = 0
        
        writer.write(img)
        cv2.imshow('history', img)
        key = cv2.waitKey(1)
        if key == 27:
            writer.release()
            break
        if key == ord(' '):
            pause()



def histogram(bit_stream):
    interval_buf = []
    dist = 0
    for bit in bit_stream:
        if bit == 0:
            dist += 1
        else:
            interval_buf.append(dist)
            dist = 0

    fig = plt.figure(figsize=(8,4), dpi=200)
    ax1 = fig.add_subplot(1,2,1)
    ax2 = fig.add_subplot(1,2,2)

    ax1.set_title('linear-scale')
    ax1.set_xlabel('count')
    ax1.set_ylabel('frequency')
    ax1.set_xlim(0,80)
    ax1.grid(True)
    ax1.hist(interval_buf, bins=80, range=(0,80), histtype='stepfilled', orientation='vertical', log=False)

    ax2.set_title('log-scale')
    ax2.set_xlabel('count')
    ax2.set_ylabel('frequency')
    ax2.set_xlim(0,80)
    ax2.grid(True)
    ax2.hist(interval_buf, bins=80, range=(0,80), histtype='stepfilled', orientation='vertical', log=True)

    plt.show()



def pulse_pitch_variation(bit_stream, sampling_rate, bit_rate):
    pulse_pitch = []
    bit_cell_ref = sampling_rate / bit_rate
    avg_bit_cell = bit_cell_ref
    ring_buf = [ bit_cell_ref for _ in range(32) ]
    ring_ptr = 0
    dist = 0
    for bit in bit_stream:
        dist += 1
        if bit == 0:
            pulse_pitch.append(avg_bit_cell)
        else:
            quantized = int((dist / bit_cell_ref) + 0.5)
            if quantized == 0:
                quantized = 0.1

            ring_buf[ring_ptr] = dist / quantized
            ring_ptr += 1
            if ring_ptr >= len(ring_buf):
                ring_ptr = 0
            avg_bit_cell = sum(ring_buf) / len(ring_buf)

            pulse_pitch.append(avg_bit_cell)
            dist = 0

    x_axis = [ i for i in range(len(pulse_pitch)) ]

    fig = plt.figure(figsize=(8,4), dpi=200)
    ax1 = fig.add_subplot(1,1,1)

    ax1.set_title('bit_cell pitch variation')
    ax1.set_xlabel('bit cell count')
    ax1.set_ylabel('bit cell pitch')
    ax1.set_ylim(0, 12)
    ax1.grid(True)
    ax1.plot(x_axis, pulse_pitch)
    plt.show()
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

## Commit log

2020-07-18 add kicad data
    [fdshield-B_Cu.gbl, fdshield-B_Mask.gbs, fdshield-B_Paste.gbp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]
2020-08-02 added fdshield DIP version design files
    [fdshield-B_Cu.gbl, fdshield-B_Mask.gbs, fdshield-B_Paste.gbp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]
2020-08-08 PCB FAB-F. Add write back feature
    [fdshield-B_Cu.gbl, fdshield-B_Mask.gbs, fdshield-B_Paste.gbp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]
2020-08-08 rename to fdshield-sop
    [fdshield-B_Cu.gbl, fdshield-B_Mask.gbs, fdshield-B_Paste.gbp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]
2020-08-09 removed old PCB design archives
2020-08-09 organized PCB design data
2020-08-10 added command interface to arduino firmware
2020-08-10 added seek command to arduino FW
2020-08-10 added schematics
2020-08-14 daily commit
    [fdshield-B_Cu.gbl, fdshield-B_Mask.gbs, fdshield-B_Paste.gbp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]
2020-08-14 document update
    [fdshield-B_Cu.gbl, fdshield-B_Mask.gbs, fdshield-B_Paste.gbp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]
2020-08-21 Same ID abort feature improved
    Same ID abort feature will be enabled only after 200ms passed from the
    top of the track.
    Added a feature to track the time of the reading pointer in the
    bitstream in the data_separator.
2020-08-22 Add read_overlap limitation logic
    Calculate the max capacity of the SPI SRAM and limit the read overlap
    parameter when it exceeds the max SPI SRAM capacity.
2020-08-22 Daily commit
    - multiple address mark support (MB8877)
    - fixed bug in drive type detection in fdcapture.ino
    [fdshield.sch]
2022-08-16 Change index hole detection algorithm
2022-08-24 Fixed bug in bs2.d77 (output file name)
    [bs2d77.py]
2022-08-24 Fixed a bug in fdcapture.ino
    Wrong RAW encode happened when the pulse pitch is too long and
    a variable 'count' get overflowed.
    [fdcapture.ino]
2022-08-26 fdcapture dumps only 'captured' data.
    previously, fdcapture dumps all data stored in the SPI SRAM regardless
    how much data is captured from the FDD.
    Now it dumps only the real, captured data portion only.
2022-08-27 Add 2HD parameter support
    - fdcapture.ino
    - Reports sampling rate (4MHz)
    - transfer.py
    - Accept 2HD as media type
    - Determine bit rate and track range from the media type.
2022-08-27 Fixed 2DD/2D step issue
    [fdcapture.ino]
2022-09-01 Update Readme. Add pulse pitch visualizer
2022-09-02 Fixed minor bug in pulse pitch viewer
    [bs_inspect.py]
2022-09-08 Added spindle_calibration_tool.py
2022-09-17 Fixed bug in bs2hfe.py (track offset table size)
    [bs2hfe.py]
2022-09-28 JP5(WG) changed from solder jumper to pin header
    [fdshield-B_Cu.gbl, fdshield-B_Mask.gbs, fdshield-B_Paste.gbp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]
2022-09-29 Added SPI SRAM overflow check
2022-09-30 PCB data update (WG) (rev_h)
    [fdshield-B_Cu.gbl, fdshield-B_Mask.gbs, fdshield-B_Paste.gbp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]
2022-10-10 Arduino timer calib. + track visualizer.
    Added 'track visualizer' in bs_inspector.py
    Added support for Arduino timer1 clock calibration.
    - Added 'M' command to measure the Arduino timer1 count speed
    - Added 'S' command to set the calibrated timer clock value
    - Changed track read and track write to use timer1 for timing
    control
    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
2022-10-10 Improved track visualizer in bs_inspect.py
    - ID-CRC error support
    - Data CRC error support
    - RNF error support
    [bs_inspect.py]
2022-10-10 Added ascii dump support in track visualizer in bs_inspect.py
2022-11-03 Add temporary code to support non-genuine Arduino Uno compatible boards.
